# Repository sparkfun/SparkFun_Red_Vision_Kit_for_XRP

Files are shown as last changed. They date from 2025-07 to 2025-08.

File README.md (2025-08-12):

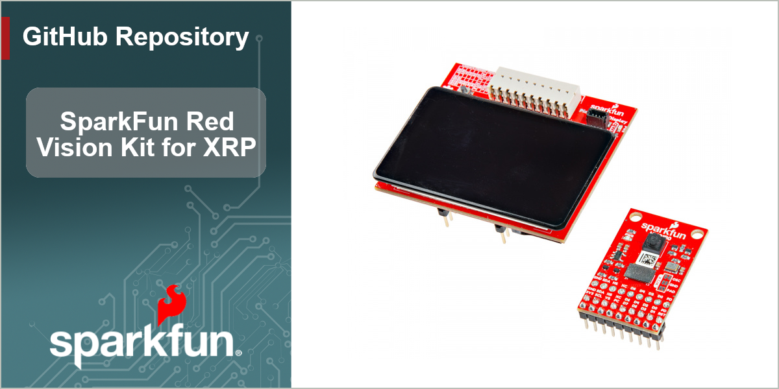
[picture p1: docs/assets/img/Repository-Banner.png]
SparkFun Red Vision Kit for XRP (https://www.sparkfun.com/sparkfun-pico-vision-kit-for-xrp.html)


[*SparkFun Red Vision Kit for XRP (KIT-28667)*](https://www.sparkfun.com/sparkfun-pico-vision-kit-for-xrp.html)

The SparkFun Red Vision Kit for XRP comes with the Red Vision Touch Display for Pico and Red Vision Camera Board - HM01B0 (Color) to add add machine vision capabilities to the Experiential Robotics Platform (XRP) Kit. This kit comes with everything you need to quickly and easily add a camera and touchscreen display to your XRP Robot with no soldering required. These boards let you add live image processing as well as advanced features including object and contour detection among others to the Experiential Robotics Platform (XRP) Kit using the SparkFun MicroPython Red Vision Code package, a MicroPython port of the popular OpenCV image processing library.

Repository Contents
-------------------

* **/Hardware** - KiCad design files (.brd, .sch)
* **/docs** - GitHub Pages documentation files

Documentation
--------------
* **[SparkFun Red Vision MicroPython Package](https://github.com/sparkfun/red_vision/tree/main)** - MicroPython package for the SparkFun Red Vision Kit for XRP.
* **[SparkFun MicroPython OpenCV](https://github.com/sparkfun/micropython-opencv)** - MicroPython port of OpenCV code library.
* **[SparkFun MicroPython Firmware Releases](https://github.com/sparkfun/micropython/releases)** - SparkFun MicroPython firmware releases.
* **[SparkFun Red Vision Kit for XRP Hookup Guide](https://docs.sparkfun.com/SparkFun_Red_Vision_Kit_for_XRP/introduction)** - Basic hookup guide for the SparkFun Red Vision Kit for XRP.

Product Versions
----------------
* [KIT-28667](https://www.sparkfun.com/sparkfun-pico-vision-kit-for-xrp.html) - Initial release of the SparkFun Red Vision Kit for XRP
* [LCD-29467](https://www.sparkfun.com/sparkfun-red-vision-touch-display-for-pico.html) - SparkFun Red Vision Touch Display for Pico (Standalone board)
* [SEN-29468](https://www.sparkfun.com/sparkfun-red-vision-camera-board-hm01b0-color.html) - SparkFun Red Vision Camera Board - HM01B0 (Color) (Standalone board)

License Information
-------------------

This product is _**open source**_! 

Please review the LICENSE.md file for license information. 

If you have any questions or concerns on licensing, please contact technical support on our [SparkFun forums](https://forum.sparkfun.com/viewforum.php?f=152).

Distributed as-is; no warranty is given.

- Your friends at SparkFun.

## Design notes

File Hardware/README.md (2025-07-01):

SparkFun <PRODUCT NAME> Design Files
=====================================

The .sch and .brd files hare are Eagle CAD schematic and PCB design files from SparkFun Electronics.
A freeware version of Autodesk Eagle can be found [here](https://www.autodesk.com/products/eagle/free-download).

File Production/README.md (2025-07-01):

SparkFun <PRODUCT NAME> Production Files
=========================================

These are the production files SparkFun uses for printing PCBs.

License Information
-------------------
This product is open source! 

The hardware is released under [Creative Commons ShareAlike 4.0 International](https://creativecommons.org/licenses/by-sa/4.0/).

Please use, reuse, and modify these files as you see fit. Please maintain attribution to SparkFun Electronics and release anything derivative under the same license.

Distributed as-is; no warranty is given.

- Your friends at SparkFun.

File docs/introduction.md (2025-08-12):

<figure markdown>
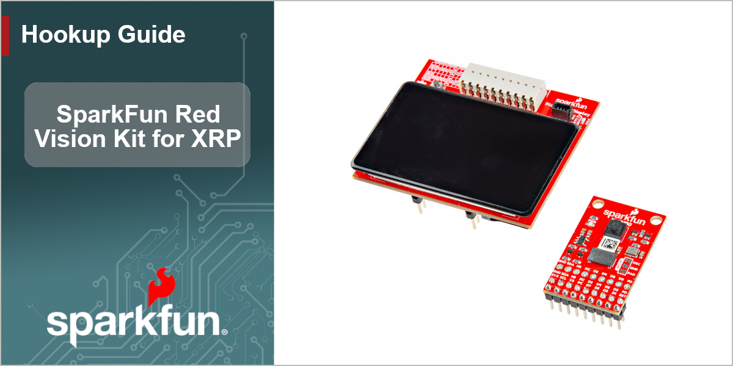
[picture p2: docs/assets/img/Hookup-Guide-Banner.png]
Banner photo for the Red Vision Kit for XRP

</figure>

The [SparkFun Red Vision Kit for XRP](https://www.sparkfun.com/sparkfun-pico-vision-kit-for-xrp.html) features the [SparkFun Red Vision Touch Display for Pico](https://www.sparkfun.com/sparkfun-red-vision-touch-display-for-pico.html) and the [SparkFun Red Vision Camera Board - HM01B0 (Color)](https://www.sparkfun.com/sparkfun-red-vision-camera-board-hm01b0-color.html) so you can add image processing and display to the SparkFun Experiential Robotics Kit (XRP). This Hookup Guide is written primarily for users with the Red Vision kit but those who have just one of these boards can follow along to some degree to get their boards up and running on an XRP or Pico. Note, all code covered here assumes use of the full Red Vision kit connected to an XRP Kit.

## Required Matierals

In order to follow along with this guide, you'll need the following materials:

* [SparkFun Red Vision Kit for XRP](https://www.sparkfun.com/sparkfun-pico-vision-kit-for-xrp.html)
* [SparkFun XRP Kit](https://www.sparkfun.com/experiential-robotics-platform-xrp-kit.html) (The Red Vision Kit does **not** work with the [Beta version](https://www.sparkfun.com/experiential-robotics-platform-xrp-kit-beta.html) of the XRP)
* [USB-C Cable](https://www.sparkfun.com/reversible-usb-a-to-c-cable-0-8m.html)

## Suggested Reading

This guide assumes users have a fully assembled and functioning XRP Kit and also is somewhat familiar with the XRP Code Editor. If you need help assembling your XRP Kit or getting started with the XRP and the XRP Code editor, please read through the following documentation:

* [XRP Users Guide](https://xrpusersguide.readthedocs.io/en/latest/course/introduction.html)
* [Experiential Robotics Platform Docs](https://introtoroboticsv2.readthedocs.io/en/latest/)

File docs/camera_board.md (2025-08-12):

Let's take a closer look at the Camera Board - HM0B10 and the hardware on it.

<figure markdown>
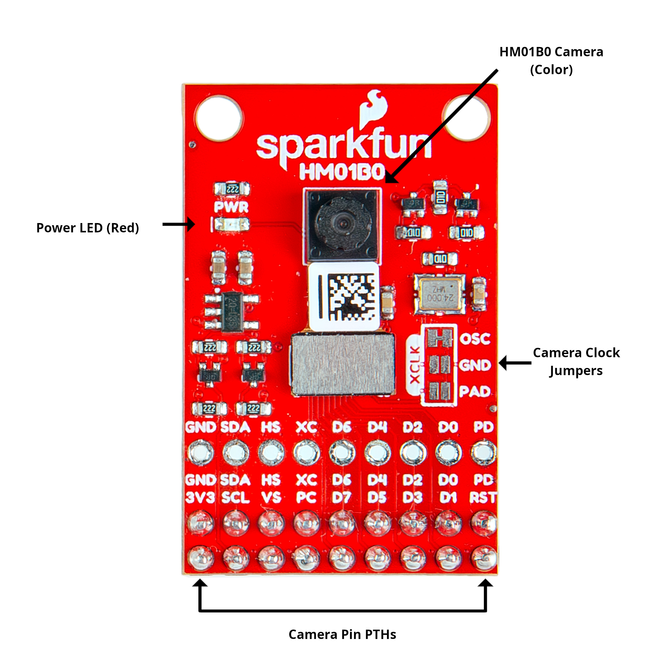
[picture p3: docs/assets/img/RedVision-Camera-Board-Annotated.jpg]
Annotated photo of the Red Vision Camera Board

</figure>

## Himax HM0B10 Camera Module (Color)

The HM0B10 camera module from Himax<sup>&reg;</sup> has a 320 x 320 pixel resolution that supports frame rates of up to 51FPS in full resolution (320x320) and up to 60FPS in windowed/QVGA (320x240) operation. The camera module also has a 2x2 monochrome binning mode that supports up to 120FPS if you're looking to maximize frame rate over resolution and color. The HM01B0 also has a motion detect feature tied to an interrupt output so you can program it to wake up your camera project whenever it senses motion. The video data interface communicates over a configurable 1, 4 or 8bit interface that features both video frame for synchronizing multiple cameras and line sync for creating a composite image from two cameras. The HM01B0 operates over a I<sup>2</sup>C serial interface with an address of <b>0x24</b>. For complete information on the HM0B10, refer to the [datasheet](https://cdn.sparkfun.com/assets/7/f/c/8/3/HM01B0-MNA-Datasheet.pdf).

## Pinout

The Camera Board breaks out all of the HM0B10's pins to three 9 pin, 0.1"-spaced plated through hole headers. The three headers are split into a single "top" header and a pair of "bottom" headers and we'll refer to them as "Top" and "Bottom" for the descriptions and tables below. Several pins are shared between the two sets. The Top header breaks out the minimum pins needed for basic use of the camera module and the Bottom header pair breaks out all the pins. This bottom pair connects directly to the 2x10 connector on the Red Vision Touch Display.

The tables below outline the pin name, type and function of the pins broken out to each header:

**Top Header Pinout**
<table>
    <tr>
        <th>Pin Label/Name</th>
        <th>Type</th>
        <th>Function</th>
    </tr>
    <tr>
        <td>GND/Ground</td>
        <td>Ground</td>
        <td>Ground</td>
    </tr>
    <tr>
        <td>SDA</td>
        <td>In/Out</td>
        <td>I<sup>2</sup>C Serial Data I/O (Open Drain)</td>
    </tr>
    <tr>
        <td>HS/HSYNC</td>
        <td>Output</td>
        <td></td>
    </tr>
    <tr>
        <td>XC/Clock</td>
        <td>Input</td>
        <td>Main/External Clock Input</td>
    </tr>
    <tr>
        <td>D6</td>
        <td>Output</td>
        <td>Data 6 Output</td>
    </tr>
    <tr>
        <td>D4</td>
        <td>Output</td>
        <td>Data 4 Output</td>
    </tr>
    <tr>
        <td>D2</td>
        <td>Output</td>
        <td>Data 2 Output</td>
    </tr>
    <tr>
        <td>D0</td>
        <td>Output</td>
        <td>Data 0 Output</td>
    </tr>
    <tr>
        <td>PD/Cam Powerdown</td>
        <td>Input</td>
        <td>Camera Voltage Regulator Enable</td>
    </tr>
</table>

**Bottom Header Pair Pinout**
<table>
    <tr>
        <th>Pin Label/Name</th>
        <th>Type</th>
        <th>Function</th>
    </tr>
    <tr>
        <td>GND/Ground</td>
        <td>Ground</td>
        <td>Ground</td>
    </tr>
    <tr>
        <td>3V3/3.3V</td>
        <td>Voltage Input</td>
        <td>Voltage Regulator 3.3V Input</td>
    </tr>
    <tr>
        <td>SDA</td>
        <td>In/Out</td>
        <td>I<sup>2</sup>C Serial Data I/O (Open Drain)</td>
    </tr>
    <tr>
        <td>SCL</td>
        <td>Input</td>
        <td>I<sup>2</sup>C Clock Signal</td>
    </tr>
    <tr>
        <td>HS/HSYNC</td>
        <td>Output</td>
        <td></td>
    </tr>
    <tr>
        <td>VS/VSYNC</td>
        <td>Output</td>
        <td>Frame Valid Output</td>
    </tr>
    <tr>
        <td>XC/Clock</td>
        <td>Input</td>
        <td>Main/External Clock Input</td>
    </tr>
    <tr>
        <td>PC/PCLOCK/SCK</td>
        <td>Output</td>
        <td>Pixel Clock or Serial Clock Output</td>
    </tr>
    <tr>
        <td>D6</td>
        <td>Output</td>
        <td>Data 6 Output</td>
    </tr>
    <tr>
        <td>D7</td>
        <td>Output</td>
        <td>Data 7 Output</td>
    </tr>
    <tr>
        <td>D4</td>
        <td>Output</td>
        <td>Data 4 Output</td>
    </tr>
    <tr>
        <td>D5</td>
        <td>Output</td>
        <td>Data 5 Output</td>
    </tr>
    <tr>
        <td>D2</td>
        <td>Output</td>
        <td>Data 2 Output</td>
    </tr>
    <tr>
        <td>D3</td>
        <td>Output</td>
        <td>Data 3 Output</td>
    </tr>
    <tr>
        <td>D0</td>
        <td>Output</td>
        <td>Data 0 Output</td>
    </tr>
    <tr>
        <td>D1</td>
        <td>Output</td>
        <td>Data 1 Output</td>
    </tr>
    <tr>
        <td>PD/Cam Powerdown</td>
        <td>Input</td>
        <td>Camera Voltage Regulator Enable</td>
    </tr>
    <tr>
        <td>RST/Reset</td>
        <td>Input</td>
        <td>Camera Voltage Regulator Reset</td>
    </tr>
</table>

## LED

The sole LED on this board is a red Power LED to indicate whenever the board has power over 3.3V. 

## Solder Jumpers

The Camera Board has six solder jumpers labeled: <b>OSC</b>, <b>GND</b>, <b>PAD</b>, <b>OSC_DIS</b>, <b>LED</b> and <b>I2C</b>. The lists below outlines each solder jumper's function, default state and any notes on their use. Note, manipulating these solder jumpers is only recommended for *advanced users* as they alter the functionality of the board, change the pins used by it and require knowledge of [working with jumper pads and PCB traces](https://learn.sparkfun.com/tutorials/how-to-work-with-jumper-pads-and-pcb-traces). 

**Oscillator Jumpers:**

These solder jumpers all adjust which oscillator source connects to the camera's external clock (XCLK) pin or to use the camera's internal oscillator. The board defaults to run at 24MHz with an on board oscillator. Make sure to only connect XCLK to a **single** source at a time otherwise unexpected behavior or damage may occur.

* <b>OSC</b>: This solder jumper enables the on board 24MHz oscillator by connecting it to the HM01B0's XCLK pin. It is CLOSED by default. Sever the trace in between the solder jumpers to open the jumper and disable the 24MHz clock source. 
* <b>PAD</b>: This solder jumper connects the HM0B10's XCLK pin to the PTH pads on the board labeled <b>XC</b> so users can connect an external clock source. The jumper is OPEN by default. Close the jumper to enable the <b>XC</b> pin. Make sure both the <b>OSC</b> and <b>GND</b> jumpers are OPEN when connecting a clock source to the <b>XC</b> pin. **Note:** When connected to the Red Vision Touch Display, this signal connects to GPIO3 on the XRP Control Board (or Pico).
* <b>GND</b>: This solder jumper pulls the HM0B10's XCLK pin to ground to enable the camera's internal 48MHz oscillator. It is OPEN by default. Close the jumper to enable the internal oscillator. Make sure both the <b>OSC</b> and <b>PAD</b> jumpers are OPEN before closing this jumper.
* <b>OSC_DIS</b>: This solder jumper controls whether the 28MHz oscillator on the board is on or off. It is OPEN by default and enables the crystal. Close the jumper to disable the 28MHz oscillator.

**Other Jumpers:**
* <b>LED</b>: The LED jumper completes the Power LED circuit and is CLOSED by default. Open the jumper to disable the Power LED.
* <b>I2C</b>: The I<sup>2</sup>C jumper pulls the camera's SDA and SCL lines to <b>3.3V</b> through a pair of resistors. This three-way jumper is CLOSED by default. Opening the jumper completely disables the pullup resistors on the SDA/SCL lines.

## Board Dimensions

The SparkFun Red Vision Camera Board - HMB010 measures 0.9" x 1.40" (22.86mm x 35.56mm) and has two mounting holes that fit a [4-40 screw]().

<figure markdown>
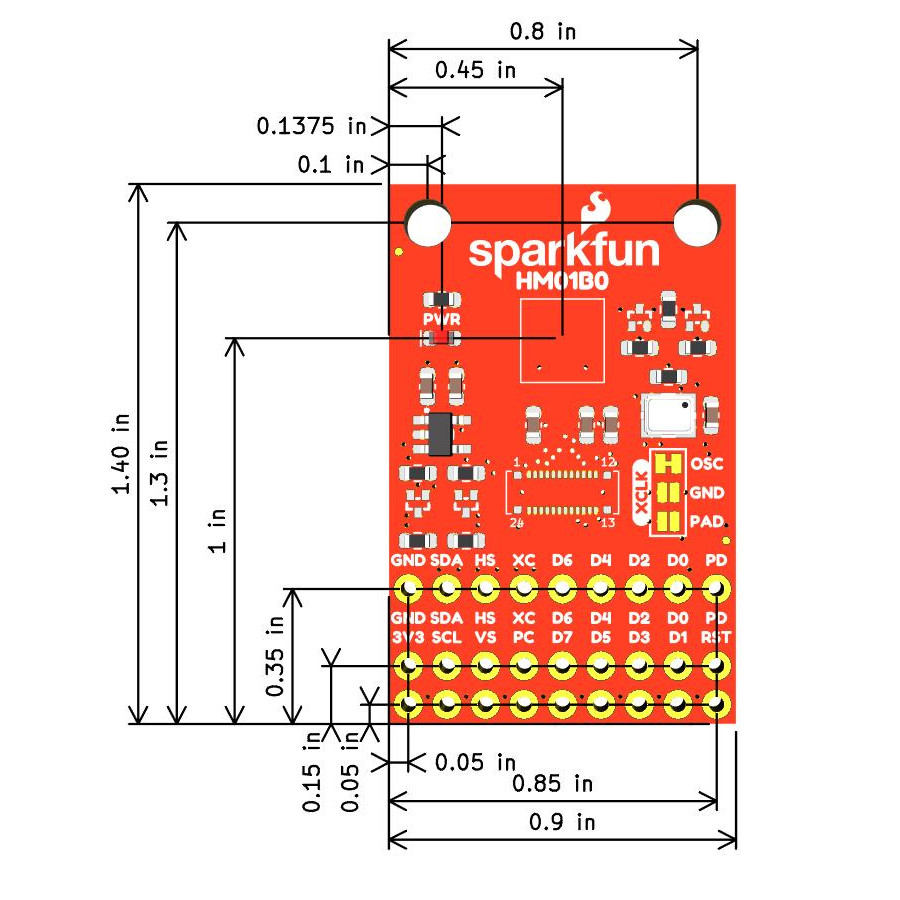
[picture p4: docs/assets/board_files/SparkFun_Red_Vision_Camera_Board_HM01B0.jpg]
Red Vision Camera Board dimensions

</figure>

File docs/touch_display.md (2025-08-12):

Let's take a closer look at the Red Vision Touch Display for Pico and the hardware included on it.

<figure markdown>
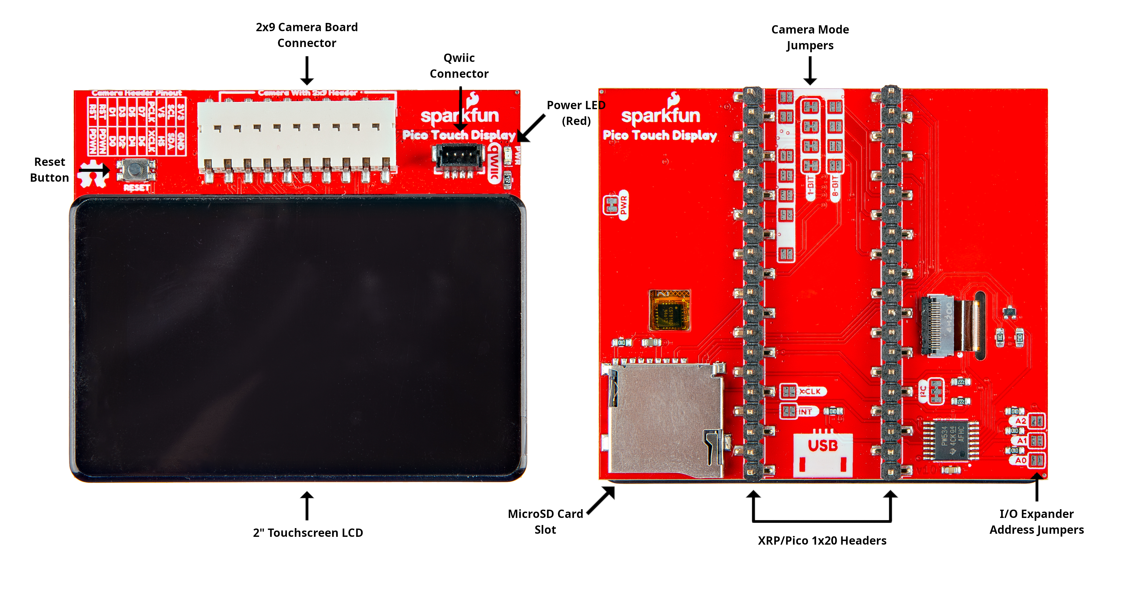
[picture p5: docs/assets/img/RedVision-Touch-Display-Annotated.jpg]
Annotated photo of the Red Vision Touch Display

</figure>

## 2" Capacitive Touch LCD

The Touch Display Board has a 2", 340x240px resolution capacitive touch LCD. 

## Connectors

### Pico Headers

We designed this board to mount directly to the XRP Control Board as well as a Rasbperry Pi Pico so it has a pair of 20 pin male headers that match the footprint of those two boards. These headers break out all the required pins for running and controlling both the display on this board as well as pins for the connected camera board. 

### Camera Connector

The Touch Display board has a 2x10 female connector to connect to the Red Vision Camera Board (or other compatible camera board, refer to [this list](https://github.com/sparkfun/red_vision?tab=readme-ov-file#hardware-support) for supported hardware). Note, the Camera Board has a 2x9 header so when connecting the two, make sure to align it to the side near the Qwiic connector. We cover this in more detail with photos in the [Hardware Assembly](../hardware_assembly.md) section further on in this guide.

### Qwiic Connector

The board has one Qwiic connector to allow users to easily add other Qwiic devices to their circuit if desired.

## GPIO Expander

The Touch Display includes a PCA9534PW GPIO expander to control several I/O (input and output) pins from the display, camera and SD card over I<sup>2</sup>C. Users can interact with the GPIO expander using the [SparkFun PCA9685 Python](https://github.com/sparkfun/qwiic_pca9685_py) package.

## &micro;SD Card Slot

The board includes a &micro;SD card slot to allow users to increase the memory capacity of a connected board; whether that be the XRP Control Board or a Pico.

## Reset Button

The reset button on the Touch Display board connects to the reset button on the XRP Control Board (or Pico) to allow easy access to reset the board.

## LED

The sole LED on this board is a red Power LED to indicate when the board has power.

## Solder Jumpers

The Red Vision Touch Display for Pico has a large amount of solder jumpers so we'll cover them in subsections. Note, manipulating these solder jumpers is only recommended for *advanced users* as they alter the functionality of the board, change the pins used by it and require knowledge of [working with jumper pads and PCB traces](https://learn.sparkfun.com/tutorials/how-to-work-with-jumper-pads-and-pcb-traces). 

### GPIO Expander Jumpers

This set of jumpers labeled <b>A0</b>, <b>A1</b> and <b>A2</b> control the I<sup>2</sup>C address of the GPIO Expander. All three jumpers are OPEN by default to set the GPIO Expander's address to <b>0x20</b>. Closing different combinations of these jumpers lets users select from eight I<sup>2</sup>C addresses. The table below outlines the different options to change the address. You can also refer to the [schematic](./assets/board_files/SparkFun_Red_Vision_Touch_Display_for_Pico.pdf) for more information.

<table>
    <tr>
        <th>I<sup>2</sup>C Address</th>
        <th>A0 State</th>
        <th>A1 State</th>
        <th>A2 State</th>
    </tr>
    <tr>
        <td>0x20 (Default)</td>
        <td>Open</td>
        <td>Open</td>
        <td>Open</td>
    </tr>
    <tr>
        <td>0x21</td>
        <td>Closed</td>
        <td>Open</td>
        <td>Open</td>
    </tr>
    <tr>
        <td>0x22</td>
        <td>Open</td>
        <td>Closed</td>
        <td>Open</td>
    </tr>
    <tr>
        <td>0x23</td>
        <td>Closed</td>
        <td>Closed</td>
        <td>Open</td>
    </tr>
    <tr>
        <td>0x24</td>
        <td>Open</td>
        <td>Open</td>
        <td>Closed</td>
    </tr>
    <tr>
        <td>0x25</td>
        <td>Closed</td>
        <td>Open</td>
        <td>Closed</td>
    </tr>
    <tr>
        <td>0x26</td>
        <td>Open</td>
        <td>Closed</td>
        <td>Closed</td>
    </tr>
    <tr>
        <td>0x27</td>
        <td>Closed</td>
        <td>Closed</td>
        <td>Closed</td>
    </tr>
</table>

The fourth jumper for the GPIO Expander controls whether or not the IC's enable pin connects to GPIO2 on the XRP Control Board. The jumper is OPEN by default. Close the jumper to connect the enable pin to GPIO2 for software control of the GPIO Expander.

### Camera Connections (DVP Interface) Jumpers

The solder jumper labeled <b>XCLK</b> allows users to generate an external clock to a connected camera from GPIO3. This jumper is OPEN by default. Closing this jumper connects the external clock pin on a connected camera to GPIO3 so make sure a connected camera is configured to use an external clock signal from this pin. **Note:** The Red Vision Camera Board included in this kit is configured to use an on-board external clock by default so *make sure* to adjust the board to use an external clock signal from GPIO3 prior to closing this jumper.

The two groups of solder jumpers labeled <b>1-BIT</b> and <b>8-BIT</b> allow users to change between running a connected camera in 1-Bit (Default) or 8-bit modes. Switching between 1-Bit and 8-Bit requires adjusting **all** of the related jumpers. For example, the board defaults to running a camera in 1-Bit mode by having **all** 1-Bit jumpers CLOSED and **all** 8-Bit jumpers OPEN. The tables below outline which pins a connected camera route to when set to run in 1-Bit or 8-Bit modes:

**1-Bit Camera Operation**
<table>
    <tr>
        <th>Camera Pin</th>
        <th>XRP/Pico Pin</th>
        <th>Notes</th>
    </tr>
    <tr>
        <td>CAM_DO</td>
        <td>GPIO12</td>
        <td>Camera Data 0 Out</td>
    </tr>
    <tr>
        <td>CAM_VS</td>
        <td>GPIO13</td>
        <td>Camera Frame Valid Output</td>
    </tr>
    <tr>
        <td>CAM_HS</td>
        <td>GPIO14</td>
        <td>Cam Line Valid Output</td>
    </tr>
    <tr>
        <td>CAM_PCLK</td>
        <td>GPIO15</td>
        <td>Camera Pixel Clock/Serial Clock Out</td>
    </tr>
</table>

**8-Bit Camera Operation**
<table>
    <tr>
        <th>Camera Pin</th>
        <th>XRP/Pico Pin</th>
        <th>Note</th>
    </tr>
    <tr>
        <td>CAM_DO</td>
        <td>GPIO8</td>
        <td>Camera Data 0 Out</td>
    </tr>
    <tr>
        <td>CAM_D1</td>
        <td>GPIO9</td>
        <td>Camera Data 1 Out</td>
    </tr>
    <tr>
        <td>CAM_D2</td>
        <td>GPIO10</td>
        <td>Camera Data 2 Out</td>
    </tr>
    <tr>
        <td>CAM_D3</td>
        <td>GPIO11</td>
        <td>Camera Data 3 Out</td>
    </tr>
    <tr>
        <td>CAM_D4</td>
        <td>GPIO12</td>
        <td>Camera Data 4 Out</td>
    </tr>
    <tr>
        <td>CAM_D5</td>
        <td>GPIO13</td>
        <td>Camera Data 5 Out</td>
    </tr>
    <tr>
        <td>CAM_D6</td>
        <td>GPIO14</td>
        <td>Camera Data 6 Out</td>
    </tr>
    <tr>
        <td>CAM_D7</td>
        <td>GPIO15</td>
        <td>Camera Data 7 Out</td>
    </tr>
    <tr>
        <td>CAM_PCLK</td>
        <td>GPIO20</td>
        <td>Camera Pixel Clock/Serial Clock Out</td>
    </tr>
    <tr>
        <td>CAM_VS</td>
        <td>GPIO21</td>
        <td>Camera Frame Valid Output</td>
    </tr>
    <tr>
        <td>CAM_HS</td>
        <td>GPIO22</td>
        <td>Cam Line Valid Output</td>
    </tr>
</table>

### Other Jumpers

The last jumpers we haven't covered are labeled <b>PWR</b> and <b>I2C</b>. The <b>PWR</b> solder jumper completes the Power LED circuit and is CLOSED by default. Open the solder jumper to disable the Power LED. The <b>I2C</b> jumper pulls the I<sup>2</sup>C data (SDA/GPIO4) and clock (SCL/GPIO5) pins to <b>3.3V</b> through a pair of <b>2.2k&ohm;</b> resistors. Open this three-way jumper to disable the pullup resistors on the I<sup>2</sup>C bus if necessary.

## Board Dimensions

The Red Vision Touch Display for Pico measures 2.00" x 2.225" (50.80mm x 56.515mm).

<figure markdown>
Red Vision Touch Display board dimensions
</figure>

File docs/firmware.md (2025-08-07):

The SparkFun Red Vision Kit for XRP requires updated firmware to run properly. This firmware updates the XRP Control Board with the right drivers to work with the Vision Kit and also includes all of the MicroPython OpenCV examples included in the package. In this section we'll go over where to find this firmware to download, how to upload it to your XRP Control Board and where to open the examples once you've assembled the Vision Kit onto your XRP Kit. 

!!! Note
    We recommend updating the firmware on the XRP Control Board prior to installing the Vision Kit boards onto it as the Touch Display makes it difficult to reach the RESET and BOOT buttons.

## Vision Kit MiroPython Firmware

First things first, we need to download the Red Vision Kit firmware UF2 file from GitHub. If you're not familiar with what a UF2 file is and want to learn more, read more about them in this [Make Code post](https://makecode.com/blog/one-chip-to-flash-them-all). The SparkFun Red Vision firmware UF2 file is available for download from the [SparkFun MicroPython Firmware Releases](https://github.com/sparkfun/micropython/releases) on GitHub. The firmware file is named **RED_VISION_MICROPYTHON_SPARKFUN_XRP_CONTROLLER** so you'll need to click the "Show all ## Files" button at the bottom of the list and then scroll down until you find the file. Download the "RED_VISION_MICROPYTHON_SPARKFUN_XRP_CONTROLLER" file and take note of where it is saved on your computer.

## Entering Boot Mode on the XRP

Next, put the XRP Control Board into Boot Mode using the following steps:

* Connect the XRP Control Board to your computer over USB-C.
* Locate the Reset and Boot buttons.
* Press and hold the BOOT button down.
* Press and release the RESET button (while still holding the BOOT button).
* Release the BOOT button and the XRP Control Board should open as a removable drive named "RP2350" on your computer.

<figure markdown>
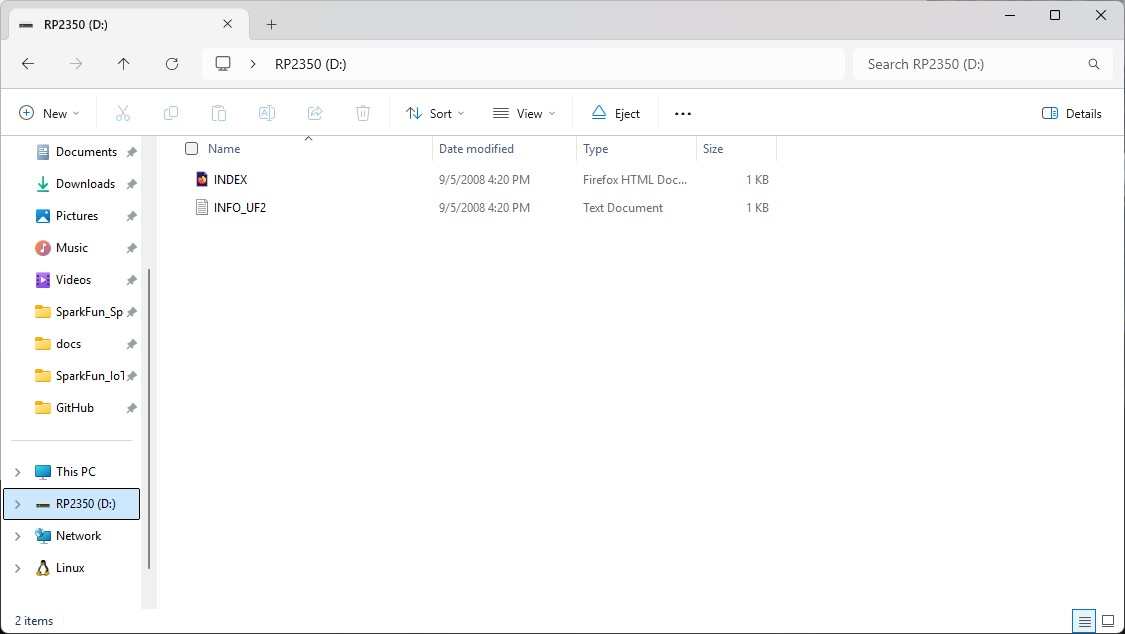
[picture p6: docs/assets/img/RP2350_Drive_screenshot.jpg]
Screenshot of XRP loaded as removable drive

</figure>

## Uploading Firmware

!!! note "Backup Your Files"
    Important! Make sure to back up any files/examples you have saved on your XRP as the new firmware *will* overwrite them.

Now that the XRP Control Board is in BOOT mode and open as a removable drive all we need to do is place the Vison Kit Firmware uF2 file in the XRP Control Board drive location. Open the download location for the firmware file and either drag the file over to the XRP drive or copy and paste it over. The upload can take about a minute to complete.

<figure markdown>
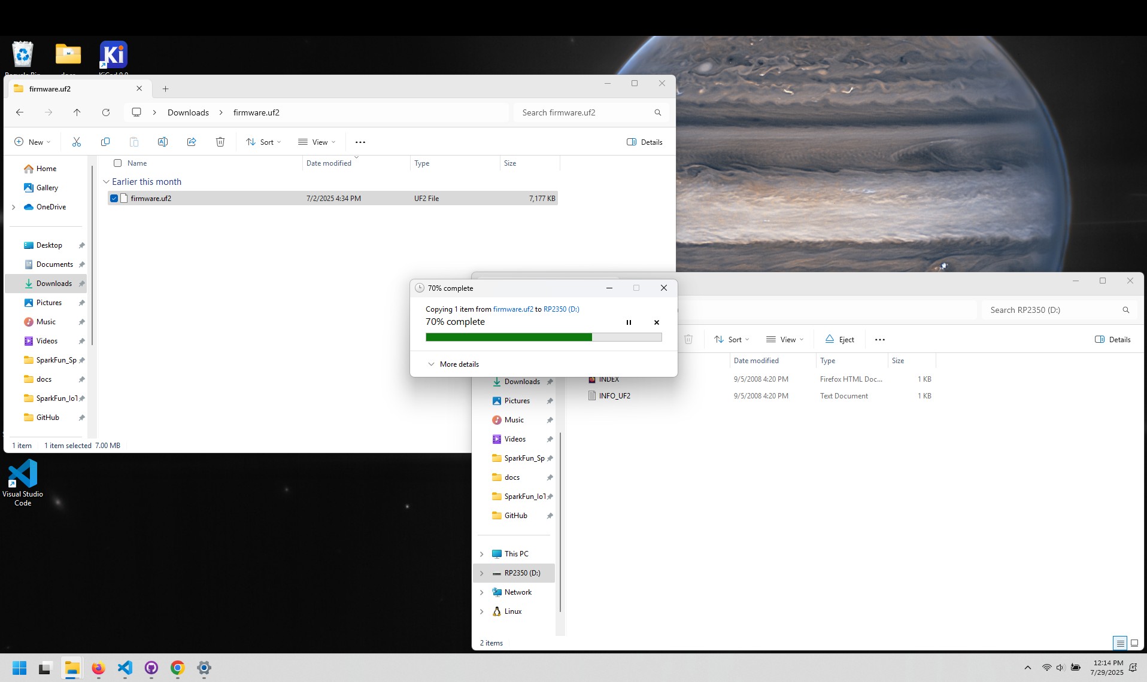
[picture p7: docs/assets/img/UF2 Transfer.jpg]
Screenshot showing firmware upload in progress

</figure>

After installing the firmware file, the XRP Control board should reset automatically and drop out of BOOT mode and we can move on to using the SparkFun MicroPython OpenCV examples.

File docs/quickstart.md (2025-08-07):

This Quick Start Guide covers how to get the SparkFun Red Vision Kit for XRP assembled and running on an XRP Kit and then use the Logo Recognition example to have the display identify and outline the SparkFun flame logo when the camera has it in view. This guide assumes users have an assembled XRP Kit, an understanding of how the kit functions as well as how to update XRP firmware and use the XRP Code Editor. If you're not familiar with those concepts or want to learn more about the boards included in the Red Vision Kit, uploading firmware and using the Red Vision MicroPython examples, read on to the Hardware and Software sections for more detailed information.

## XRP Red Vision Firmware

!!! note "Important!"
    Updating the firmware on the XRP Control Board will overwrite any files or settings saved on the board. Make sure to back up the contents of your XRP before updating the firmware.

Putting the XRP in Boot mode with the Red Vision Kit connected to it is a bit difficult so we'll update the firmware before connecting the Red Vision Kit with the following steps:

* Plug the XRP Control Board into your computer over USB-C.
* Download the latest release of the Red Vision MicroPtyhon Firmware from [GitHub](https://github.com/sparkfun/micropython/releases)
    * On the MicroPython releases page, click the "Show all ## assets" button at the bottom of the list and then download the UF2 file named **RED_VISION_MICROPYTHON_SPARKFUN_XRP_CONTROLLER**
* Put the XRP Control Board into BOOT mode with the following steps:
    * Press and hold the BOOT button
    * Press and release the RESET button (while holding the BOOT button)
    * Release the BOOT button.
    * Ensure the XRP Control Board appears as a removable storage device named "RP2350".
* Locate the "RED_VISION_MICROPYTHON_SPARKFUN_XRP_CONTROLLER" Firmware UF2 file and drag or copy/paste the file into the "RP2350" removable drive (This can take a while to complete.)

## Red Vision Kit Assembly with XRP

With the firmware updated, unplug the Control Board, power down the robot and then move on to assembling the Red Vision Kit with the following steps:

* Connect the Red Vision Camera Board to the Red Vision Touch Display for Pico taking care to align the Camera Board's 2x9 header to the LEFT side of the Touch Display's 2x10 connector. Refer to the photo below for proper alignment:

<figure markdown>
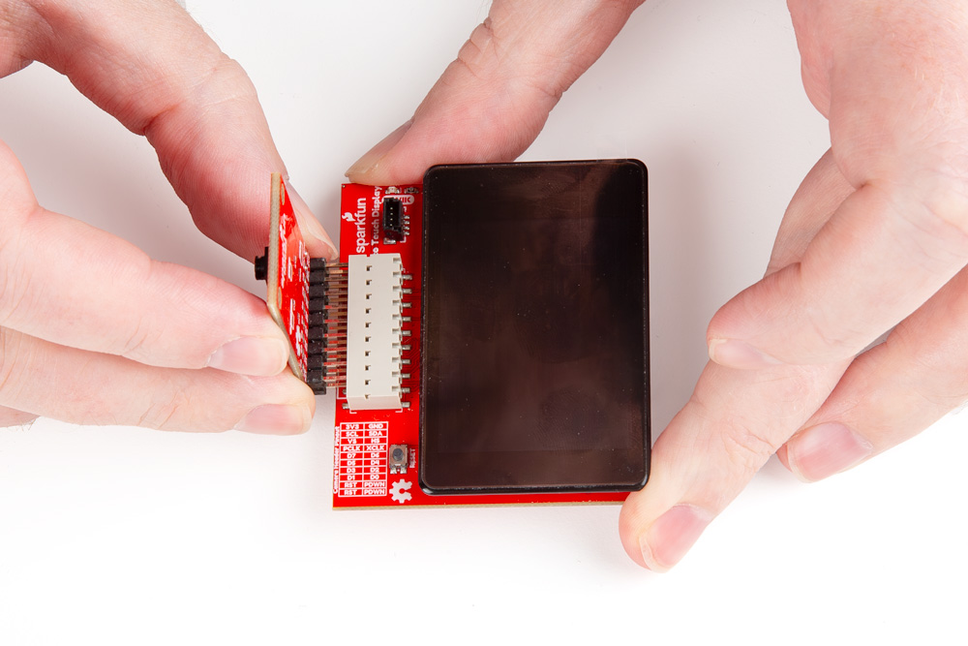
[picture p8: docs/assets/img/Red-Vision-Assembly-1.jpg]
Photo showing Camera Board connected to the Touch Display board

</figure>

* Plug the Red Vision Touch Display into the Control Board taking care to plug it into the "middle" set of headers on the Control Board:

<figure markdown>
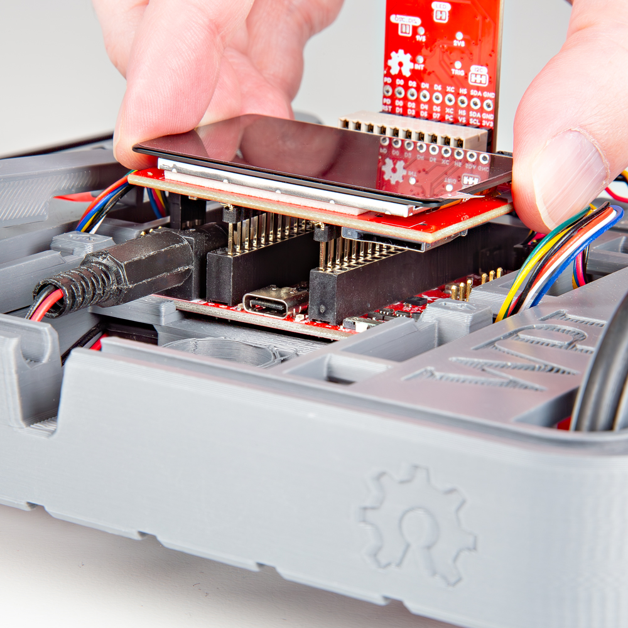
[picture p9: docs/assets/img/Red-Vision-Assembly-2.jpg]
Photo showing Touch Display connecting to the Control Board

</figure>

Take care to make sure the Pico Touch Display is plugged in facing toward the *front* of the XRP robot and is connected fully to the correct set of headers. It is possible to connect only one set of pins on the Touch Display board to the XRP Control Board's headers and this can cause damage to the boards in the Red Vision Kit. If your assembly looks like the photo below, do *not* power up the board and reseat the Touch Display:

<figure markdown>
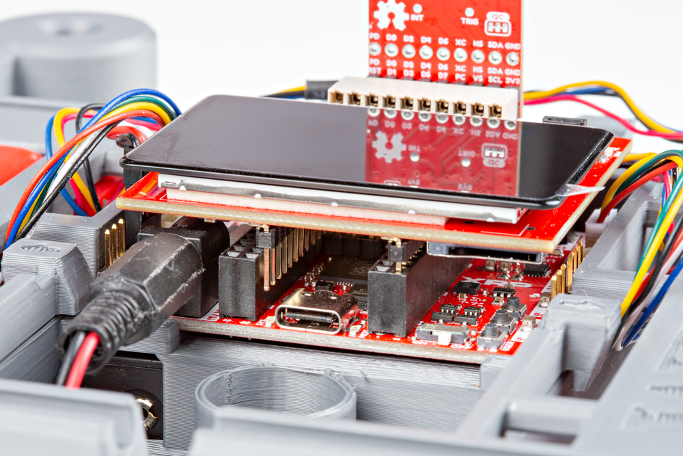
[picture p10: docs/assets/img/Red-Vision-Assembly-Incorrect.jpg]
Photo showing incorrect seating of Touch Display board

</figure>

## Example Code

Now that we've got the proper firmware installed and the Red Vision Kit connected to the XRP robot, let's take a look at the SparkFun Logo Recognition example included with the firmware. Upload the example by following the steps below:

* Open the [XRP Code Editor](https://xrpcode.wpi.edu/) in a Chromium<sup>&trade;</sup>C based browser (Chrome, Edge, etc.)
    * If you have not already, set the main power switch on the XRP Control Board to "On". The XRP Code Editor has a pop-up for this as well if you try and run code without the board powered on fully.
* Connect the XRP to the Code Editor. The window may open a pop-up asking to update the firmware. Click "Cancel" as updating the firmware will overwrite the MicroPython OpenCV firmware. A second pop-up may open asking to update libraries, click "Ok" to update the libraries. This will *not* affect the behavior or examples and is necessary to run other XRP examples.
* Open the folder named "red_vision_examples" and double click the file named "ex06_detect_sfe_logo.py" to open the code.
* Next, click the green "RUN" button in the top-right of the XRP Code Editor window.
* With the code running, we've printed out a black and white image with three objects on it; a star, the SparkFun flame and a heart. When holding it in front of the camera it should outline it and give information on the size and location of the logo. If you'd like to replicate this at home, just hold up your SparkFun red box or another SparkFun board point the logo on it at the camera. It should identify it; outline it and give information on the size and location of the logo similarly to the photo below:

<figure markdown>
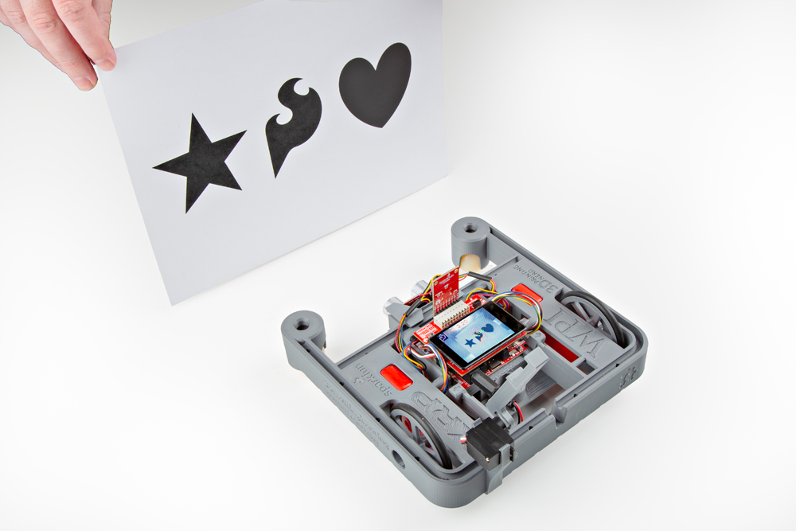
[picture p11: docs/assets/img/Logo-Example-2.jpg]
Photo showing the SparkFun logo detected and displayed on the Touch Screen display

</figure>

This close-up photo offers a better view of what the Touch Screen Display shows when the SparkFun logo is detected in camera frame. You can see in the top left what contour the code is looking for, the bounding box and outline of the logo along with information on the position of the logo's center on the screen (green numbers) and the size of the bounding box (white numbers).

<figure markdown>
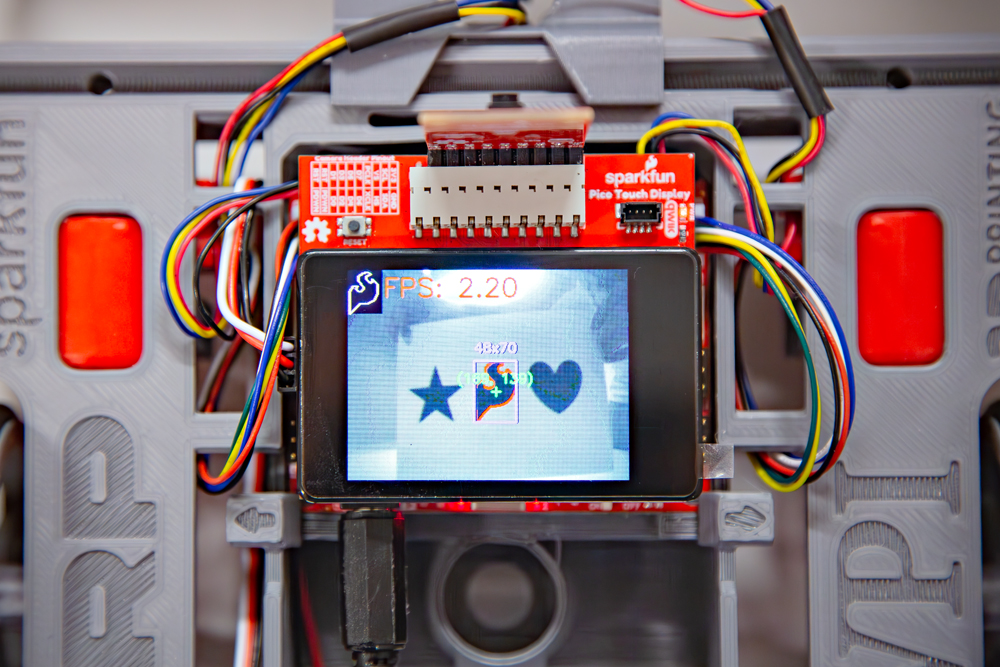
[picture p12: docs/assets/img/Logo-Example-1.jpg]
Close up photo showing the SparkFun logo detected and outlined on the Touch Screen display

</figure>

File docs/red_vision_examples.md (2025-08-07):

Now that we have the XRP Code editor up and running with our XRP Kit connected, let's take a look at some of the examples.

## Example 01 - Hello OpenCV

The first example is set up as a hardware test for the Touch Display board and the LCD. It initializes the display and creates a template image of text and shapes. On the left-hand side of the XRP Code editor, open the Red Vision Examples folder and double-click on "ex01_hello_opencv.py". Once it opens, click the green "Run" button in the top-right of the window. You should see the display initialize and then show the image below:

<figure markdown>
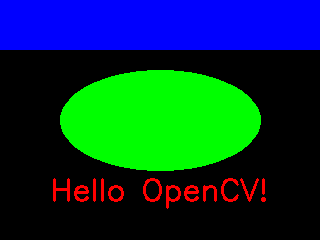
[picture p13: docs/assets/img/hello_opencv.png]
Demo image from Example 01 - Hello Open CV

</figure>

## Example 02 - Camera

The second example performs a similar hardware test but this time for the Camera Board and the HM0B10. It initializes both the camera and display, shows a quick splash image and then shows whatever the camera sees on the display. In the Red Vision Examples folder, double-click on "ex02_camera.py". After opening the file, click the "Run" button and you should see the display initialize with the splash screen pictured below followed by a greyscale stream of what the camera is viewing. 

<figure markdown>
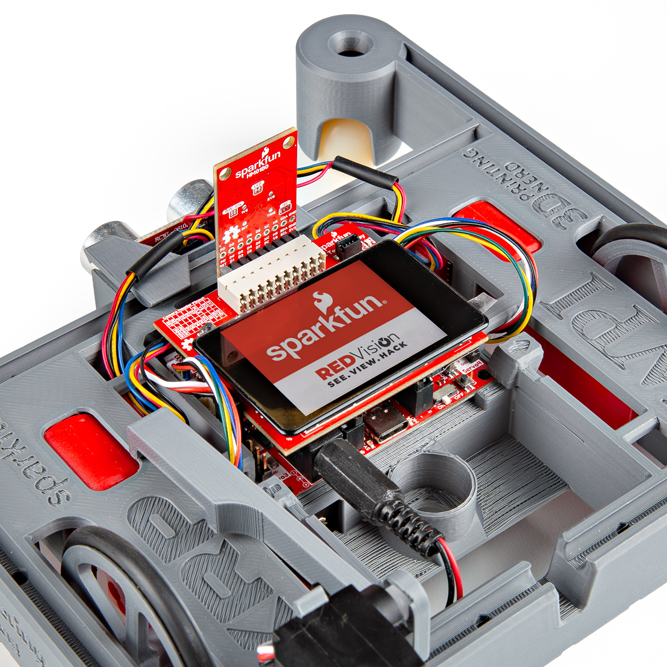
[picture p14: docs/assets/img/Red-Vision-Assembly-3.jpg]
Photo of splash screen on the Touch Display mounted on the XRP Robot

</figure>

Try moving the camera around or placing objects in front of it to test the video stream.

## Example 03 - Touch Screen

The third example tests the touch screen functionality by "turning on" pixels touched by a finger or other capacitive source (stylus, etc.). Double-click on "ex03_touch_screen.py" in the OpenCV Examples folder and click the "Run" button. The screen initializes with the same splash display as before and then follows it with a black screen with "Touch to Draw" printed in white text at the top of the screen. Try moving your finger across the display to draw or write something and you should see the display update following that path. It's not extremely precise as it's just a 240x240px display but you can draw a frumpy smiley face like the image below:

<figure markdown>
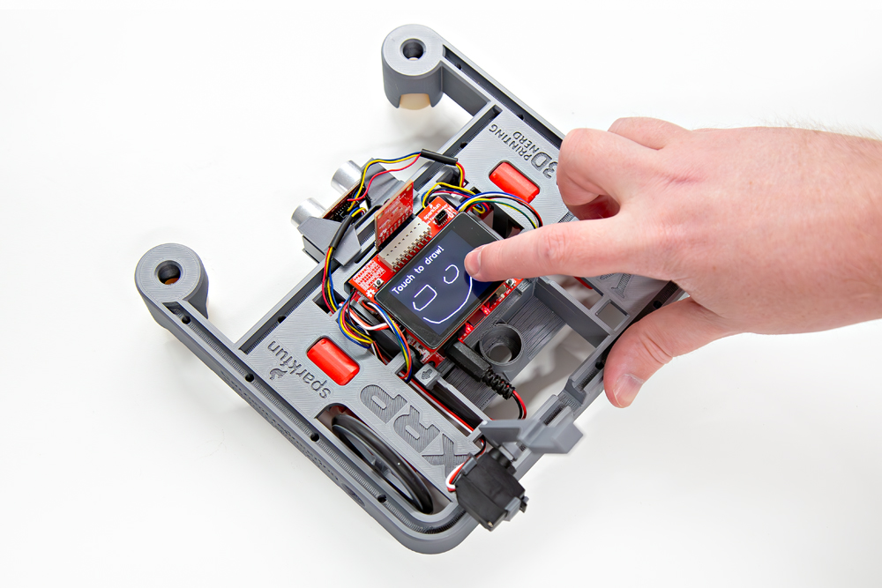
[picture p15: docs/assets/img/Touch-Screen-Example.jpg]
Photo showing a smiley face drawn on the touch display.

</figure>

## Example 06 - Detect SFE Logo

The sixth example demonstrates how to use a basic vision processing pipeline. A pipeline is a sequence of steps used to extract meaningful data from an image. In this example, the pipeline attempts to have the camera detect the SparkFun flame logo using contour matching. In the XRP Code Editor, double click "ex_06_detect_sfe_logo.py" to open the example and click the "Run" button.

While the example is running, if the camera detects the logo in frame, it outlines it on the display and draws a bounding box along with a target over the center of the logo to show how to get useful numerical data from an image such as the position and size of an object:

<figure markdown>
Photo showing SparkFun flame detected and outlined on Touch Display
</figure>

For our testing we have a nice big black and white print out with three objects on it; a star, SparkFun flame and heart. Now you may not have the same thing handy but if you've got a SparkFun red box or SparkFun board, try holding that up to the camera with the SparkFun flame in frame and the code should recognize it and outline it on the display just like the image above.

## XRP Example 01 - Touch Drive

The next two examples are nested in another folder within the "red_vision_examples" folder called "xrp_examples". Click on the "xrp_examples" folder to open it up and then double-click on the example named "ex01_touch_screen_drive.py" to open the code. This example creates a simple touch screen interface to drive the XRP robot. It displays four arrows to drive the robot forwards, backwards and to turn it left and right along with a stop button to exit the example.

<figure markdown>
Short video showing XRP robot turning from Touch Display input
</figure>

## XRP Example 02 - Grab Orange Ring

The second XRP example demonstrates how to combine object presence and position along with driving the robot towards the detected object. This takes a lot of what we've covered in the previous examples and puts them all together. Open the example in the XRP Code Editor by double clicking "ex02_grab_orange_ring.py". This example requires a bit of setup so it waits on a user input from the USER button on the XRP Control Board. We start by lining the robot up facing the orange ring so the camera identifies the object, outlines it and gets positional and distance data to the ring:

<figure markdown>
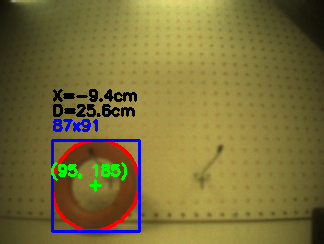
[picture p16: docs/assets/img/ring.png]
Photo showing camera view of the orange ring

</figure>

### Calculating Distance and Center Offset

Look closely at the image and you'll see the ring is not just outlined with pixel position data (95, 185), it also shows information on the offset from center of the camera's point of view (X=-9.4cm) as well as the approximate distance to the ring (D=25.6cm). We calculate the distance to the ring using the following formula: 

distance_cm = diameter_cm * focal_length_px / diameter_px

We're solving for "distance_cm" so we need the real world diameter of the ring (diameter_cm=12.7cm), the focal length pixel size (focal_length_px = 660 / 3.6) and the diameter of the ring in pixels (diameter_px = max(width, height)). 

Now that we have the approximate distance, we use that information to solve for how far left (negative units) or right (positive units) the ring is from the center in real world units using the following formula:

position_x_cm = distance_cm * position_x_px / focal_length_px

In the image above you'll see this ends up measuring as -9.4cm so the camera sees the ring as roughly 9.4cm left of center.

### User Input and Movement

Alright, that's enough math, let's see the robot move and grab the ring! Once you see the ring outlined on the Touch Display with values for distance and offset, press the USER button and the XRP robot will start navigating toward the ring and once it thinks it's in the right spot will lift the servo arm to grab the ring:

<figure markdown>
Video showing XRP robot driving toward and lifting the orange ring
</figure>

### Tips for Recreating Grab Ring Example

This example can be difficult to recreate on your own as it's looking for a specific object; an orange ring that is 12.7cm in diameter. If you'd like to try and recreate this example, you'll need to start with a ring roughly the same size and then adjust a few sections of the code depending on the size and color of the ring. The example specifically is looking for orange pixels so if your ring is a different color, you'll need to adjust the hue, saturation and value bounds for the color of your ring:

``` py
    # Here we use the `cv.inRange()` function to find all the orange pixels.
    # This outputs a binary image where pixels that fall within the specified
    # lower and upper bounds are set to 255 (white), and all other pixels are
    # set to 0 (black). This is applied to the HSV image, so the lower and upper
    # bounds are in HSV color space. The bounds were determined experimentally:
    # 
    # Hue: Orange hue is around 20, so we use a range of 15 to 25
    # Saturation: Anything above 50 is saturated enough
    # Value: Anything above 30 is bright enough
    lower_bound = (15, 50, 30)
    upper_bound = (25, 255, 255)
```

Next, measure the diameter of the ring and adjust line 122 in the example with the diameter in centimeters (cm):

``` py
diameter_cm = 12.7
```

Finally, this example attempts to drive the center of the XRP robot toward the orange ring so you'll need to position the servo arm on the front of the XRP robot as close as possible to the center of the robot similar to the position shown in the photo below:

<figure markdown>
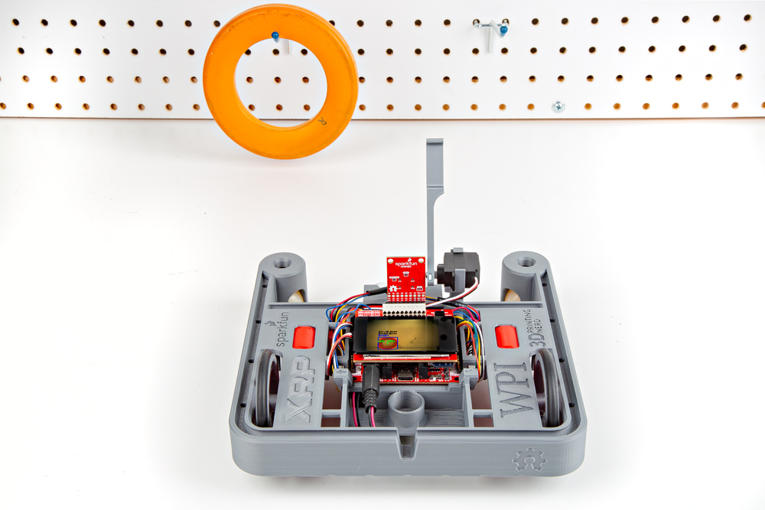
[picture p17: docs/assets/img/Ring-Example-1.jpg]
Photo showing servo arm positioned for Grab Orange Ring example

</figure>

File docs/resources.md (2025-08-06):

For more information about the Red Vision Kit for XRP along with the two boards included in it, check out the following resources:

**Red Vision Pico Touch Display**
* [Schematic](./assets/board_files/)
* [KiCad Files](./assets/board_files/SparkFun_Pico_Touch_Display.zip)
* [Board Dimensions](./assets/board_files/SparkFun_Red_Vision_Touch_Display_for_Pico.jpg)
* [GitHub Repository](https://github.com/sparkfun/SparkFun_Red_Vision_Touch_Display_for_Pico)

**Red Vision Camera Board - HM01B0 (Color)**
* [Schematic](./assets/board_files/)
* [KiCad Files](./assets/board_files/SparkFun_Camera_Board_HM01B0.zip)
* [Board Dimensions](./assets/board_files/SparkFun_Red_Vision_Camera_Board_HM01B0.jpg)
* [HM01B0 Datasheet](https://cdn.sparkfun.com/assets/7/f/c/8/3/HM01B0-MNA-Datasheet.pdf)
* [GitHub Repository](https://github.com/sparkfun/SparkFun_Red_Vision_Camera_Board_HM01B0)

**SparkFun MicroPython and Red Vision Code**
* [SparkFun MicroPython Firmware Releases](https://github.com/sparkfun/micropython/releases)
* [SparkFun Red Vision Code Package](https://github.com/sparkfun/red_vision)
* [SparkFun MicroPython OpenCV Port](https://github.com/sparkfun/micropython-opencv)

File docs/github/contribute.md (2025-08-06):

# Contribute: Make an Augmentation!
Spot an improvement opportunity? Feel free to contribute to our open-source design and documentation. 

## :material-file-document-multiple:&nbsp;Improve our Documentation
All of this documentation can be modified by you! Please help us make it better.

* These pages are contained in the [`docs` folder](https://github.com/sparkfun/SparkFun_Red_Vision_Kit_for_XRP/tree/main/docs) of the [SparkFun Ambient Light Sensor - VEML7700 repository](https://github.com/sparkfun/SparkFun_Red_Vision_Kit_for_XRP).

<!-- ### :material-source-pull:&nbsp;Submit a Correction -->
### Submit a Correction

1. With a GitHub account, [fork this repository](https://github.com/sparkfun/SparkFun_Red_Vision_Kit_for_XRP/fork).
2. Add your corrections or improvements to the markdown file.
3. File a pull request with your changes, and enjoy making the ~~words~~ ~~worlds~~ world a better place.
	* Once received, the documentation specialist will automatically be notified.
	* We will review your suggested improvements to make sure they are correct and fit within our documentation standards.

## :material-cog:&nbsp;Improve our Hardware Design
All of our designs are open-source! Please help us make it better.

* Our board design files are contained in the [`Hardware` folder](https://github.com/sparkfun/SparkFun_Red_Vision_Kit_for_XRP/tree/main/Hardware) of the [SparkFun Ambient Light Sensor - VEML7700 repository](https://github.com/sparkfun/SparkFun_Red_Vision_Kit_for_XRP).

<!-- ### :material-source-pull:&nbsp;Submit a Design Enhancement -->
### Submit a Design Enhancement

1. With a GitHub account, [fork this repository](https://github.com/sparkfun/SparkFun_Red_Vision_Kit_for_XRP/fork).
2. Add your design augmentation(s)
3. File a pull request with your changes, and enjoy making the ~~words~~ ~~worlds~~ world a better place.
	1. Once received, the engineer in charge of the original design will automatically be notified.
	2. We will review your suggested improvement(s) to verify that they are within our board design standards and meet our product design requirements.
	3. If approved, we will flag these changes for our next board revision. Congrats! 🍻

		!!! info
			Even if your suggestion is accepted, these changes may not be immediately available for purchase. We may have to cycle through our current product inventory first.

## Contributors&nbsp;:clap:
Let's provide some recognition to the contributors for this project!

GitHub Contributors Image
<br>


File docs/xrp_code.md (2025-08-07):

The SparkFun Red Vision Kit for XRP and SparkFun MicroPython OpenCV port can work on any MicroPython but since this guide focuses around using these boards on the XRP Kit, we'll be showing how to use these examples with the XRP Code Editor as it's tailored specifically to work with the XRP. 

## XRP Code Editor

The [XRP Code Editor](https://xrpcode.wpi.edu/) is a specialized web-based code editor for the XRP Kit to allow users to program in both Blocky and Python environments. We'll be using the Python environment. Note, the XRP Code Editor is only supported in Chromium<sup>&trade;</sup>C based browsers (Chrome, Edge, etc.).

### Connect XRP

First we need to connect the XRP to the XRP Code Editor by clicking the white "CONNECT XRP" button in the top right of the window and select "CONNECT VIA USB" in the pop-up window. Once the XRP connects you may see a pop-up asking to update the firmware. Click "CANCEL" as updating the firmware overwrites the Red Vision firmware we just installed:

<figure markdown>
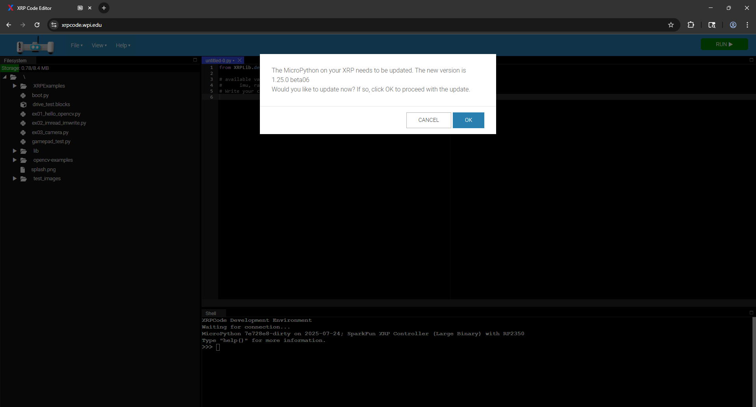
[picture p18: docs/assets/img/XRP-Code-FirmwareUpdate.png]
Screenshot showing update firmware pop-up in XRP Code Editor

</figure>

Now that we've got the XRP connected to the XRP Code Editor, we can move on to running the examples for the Red Vision Kit.

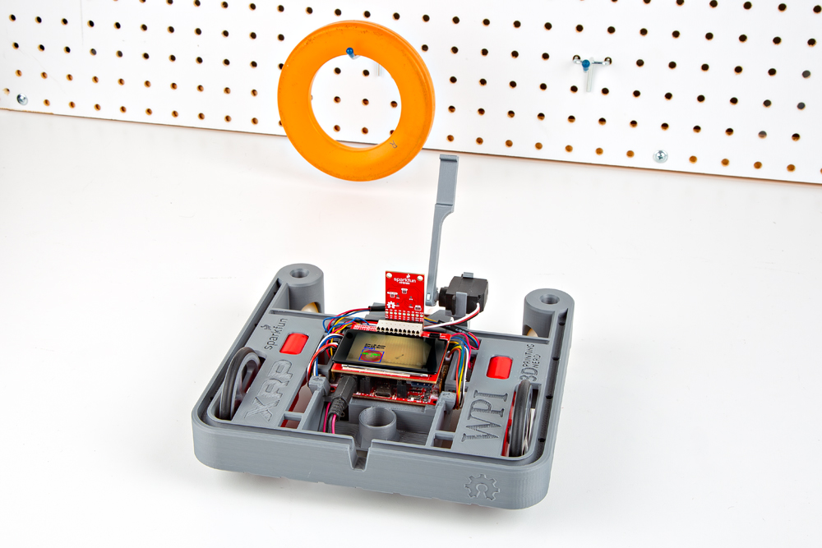
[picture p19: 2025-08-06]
docs/assets/img/Ring-Example-2.jpg

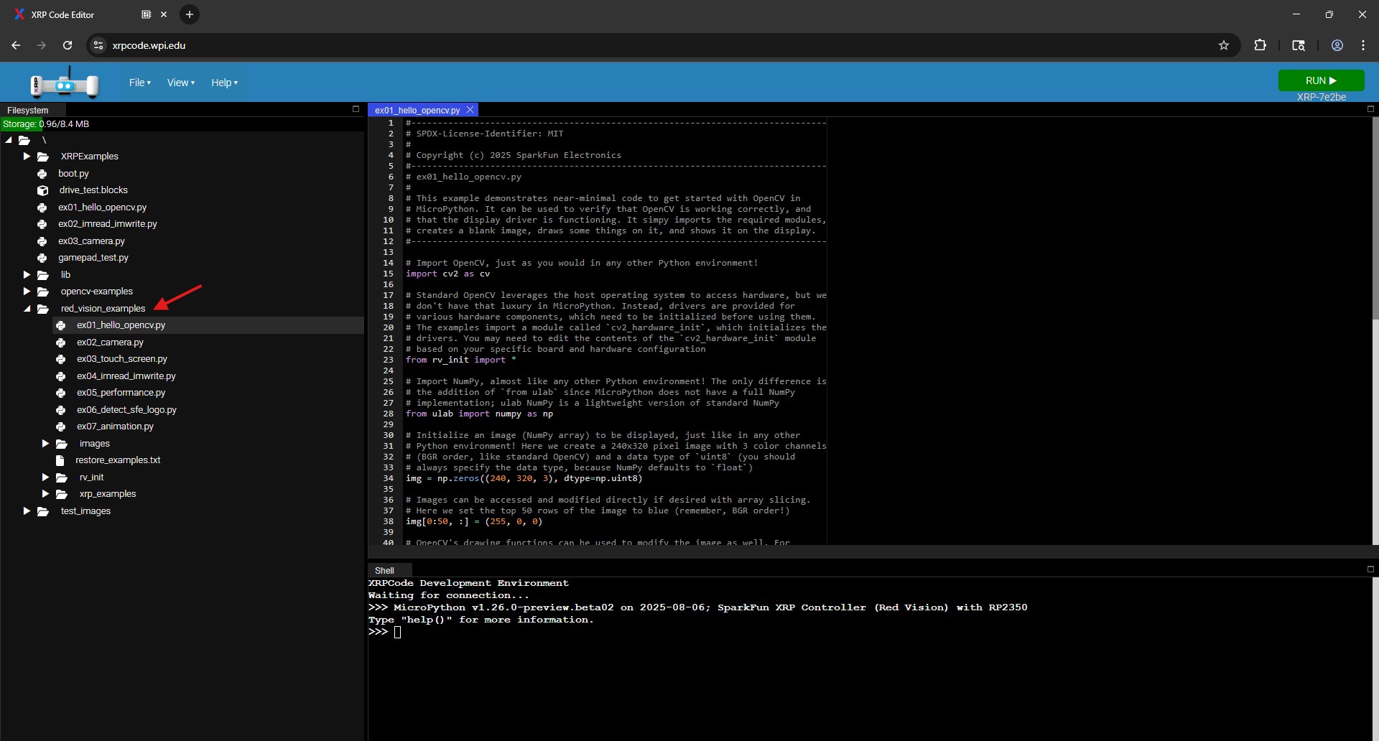
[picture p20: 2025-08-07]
docs/assets/img/XRP-Code-Red-Vision.jpg

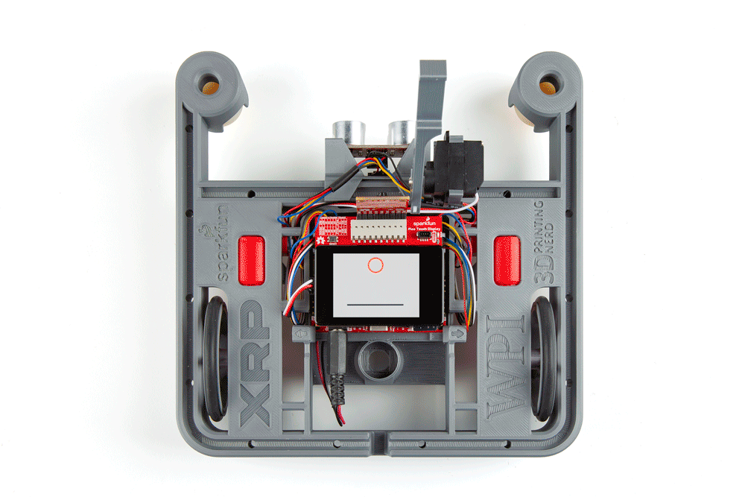
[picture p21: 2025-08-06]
docs/assets/img/Red-Vision-GIF-Bounce-Animation.gif

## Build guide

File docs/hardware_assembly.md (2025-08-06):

Now that we're familiar with the Vision Kit's Camera Board andTouch Display and have the updated firmware installed on the XRP Control Board, it's time to connect everything up to the XRP Kit.

## Connect Camera Board and Touch Display

Start by connecting the Camera Board to the Touch Display by plugging the 2x9 header on the Camera Board into the 2x10 header on the Touch Display. **IMPORTANT**: Make sure to align the Camera Board to the "LEFT" side of the 2x10 header on the Red Vision Touch Display like the photo below shows:

<figure markdown>
Photo showing Camera Board plugged into Touch Display
</figure>

## Connect Touch Display to XRP Control Board

Next, carefully align the pins on the bottom of the Red Vision Touch Display with the "Inner/Center" pair of connectors on the XRP Control Board like the photo below:

<figure markdown>
Photo showing Touch Display being connected to XRP Kit
</figure>

Take care to make sure the Red Vision Touch Display is plugged in facing toward the FRONT of the XRP robot and is connected fully to the correct set of headers. It is possible to connect only one set of pins on the Touch Display board to the XRP Control Board's headers and this can cause damage to the boards in the Red Vision Kit. If your assembly looks like the photo below, do *not* power up the board and reseat the Touch Display:

<figure markdown>
Photo showing incorrect seating of Touch Display board
</figure>

Now that we've got our Red Vision Kit assembled and connect to the XRP robot, let's move on to some code examples!

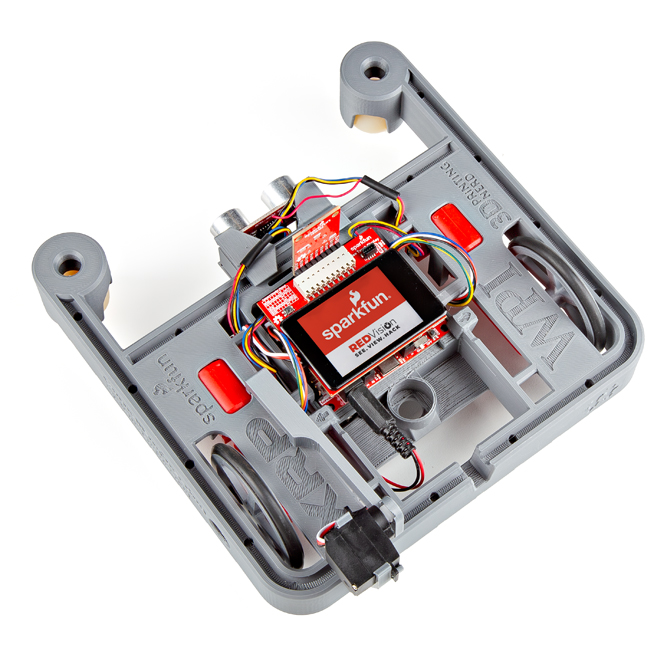
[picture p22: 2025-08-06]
docs/assets/img/Red-Vision-Assembly-4.jpg

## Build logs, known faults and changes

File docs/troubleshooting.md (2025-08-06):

## Red Vision Assembly Tips

### Camera Board Alignment

Make sure to align the Camera Board to the "LEFT" side of the 2x10 header on the Red Vision Touch Display like the photo below shows:

<figure markdown>
Photo showing Camera Board plugged into Touch Display
</figure>

### Touch Display Alignment

Take care to make sure the Red Vision Touch Display is plugged in facing toward the FRONT of the XRP robot and is connected fully to the correct set of headers. It is possible to connect only one set of pins on the Touch Display board to the XRP Control Board's headers and this can cause damage to the boards in the Red Vision Kit. If your assembly looks like the photo below, do *not* power up the board and reseat the Touch Display:

<figure markdown>
Photo showing incorrect seating of Touch Display board
</figure>

## SparkFun Red Vision Code Package Tips

The SparkFun MicroPython OpenCV port's [ReadMe file](https://github.com/sparkfun/red_vision?tab=readme-ov-file#sparkfun-red-vision) has comprehensive information about the entire package including detailed installation instructions, supported hardware, included OpenCV functions with descriptions of how to use them and much more.

### Hardware Configuration

The MicroPython port of OpenCV depends on hardware drivers to interface with cameras and displays. Drivers are built into the firmware, so there is no need to install them manually. 

An example module called cv2_hardware_init is imported by all examples to initialize the drivers. You will likely need to edit the files for your specific hardware and board configuration.

The standard MicroPython OpenCV firmware UF2 file contains a hardware configuration file set up specifically to work with the XRP Kit. If you're not using the Red Vision Kit with an XRP, you'll most likely need to go and change the pin assignments in the [cv2_hardware_init](https://github.com/sparkfun/micropython-opencv/blob/features_for_launch/examples/cv2_hardware_init)

### Performance

The main version of OpenCV is designed to run on desktop machines with orders of magnitude more processing power and speed so temper your expectations for the performance of this OpenCV port. 

## General Troubleshooting

!!! note
    <span class="glyphicon glyphicon-question-sign" aria-hidden="true"></span>
        <strong> Not working as expected and need help? </strong> <br /><br />

    If you need technical assistance and more information on a product that is not working as you expected, we recommend heading on over to the <a href="https://www.sparkfun.com/technical_assistance">SparkFun Technical Assistance</a> page for some initial troubleshooting. <br /><br />

    <div style="text-align: center"><a href="https://www.sparkfun.com/technical_assistance" target="sfe_technical_assistance" class="md-button">SparkFun Technical Assistance Page</a></div>

    If you don't find what you need there, the <a href="https://community.sparkfun.com/">SparkFun Forums</a> are a great place to find and ask for help. If this is your first visit, you'll need to create a forum account to search product forums and post questions.<br /><br />

    <div style="text-align: center"><a href="https://community.sparkfun.com/" class="md-button md-button--primary">Log Into SparkFun Forums</a></div>

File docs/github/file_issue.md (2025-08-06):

# Did we make a mistake?

Spot something wrong? Please let us know. 

## Discrepancies in the Documentation

All of our documentation can be modified by you! Please help us make it better.

* The documentation files for these pages are contained in the [`docs` folder](https://github.com/sparkfun/SparkFun_Red_Vision_Kit_for_XRP/tree/main/docs) of the [SparkFun Ambient Light Sensor - VEML7700 repository](https://github.com/sparkfun/SparkFun_Red_Vision_Kit_for_XRP).

### 🔍 Spot something wrong?

If a section of the documentation is incorrect, please [open an issue](https://github.com/sparkfun/SparkFun_Red_Vision_Kit_for_XRP/issues) and let us know.

### Do you have a suggested correction?

1. With a GitHub account, [fork this repository](https://github.com/sparkfun/SparkFun_Red_Vision_Kit_for_XRP/fork).
2. Add your correction(s) or improvement(s) to the markdown file(s)
3. File a pull request with your changes, and enjoy making the ~~words~~ ~~worlds~~ world a better place.
	* Once received, the documentation specialist will automatically be notified.
	* We will review your suggested improvement(s) to make sure they are correct and fit within our documentation standards.

## Problems in the Hardware Design

All of our designs are open-source! Please help us make it better.

* Our board design files are contained in the [`Hardware` folder](https://github.com/sparkfun/SparkFun_Red_Vision_Kit_for_XRP/tree/main/Hardware) of the [SparkFun Ambient Light Sensor - VEML7700 repository](https://github.com/sparkfun/SparkFun_Red_Vision_Kit_for_XRP).

### Does something not make sense? 🤔

If part of the design is confusing, please [open an issue](https://github.com/sparkfun/SparkFun_Red_Vision_Kit_for_XRP/issues) and let us know.

### Did we forget to include an important function of the board? 🤦

If part of the board's functionality is missing, please [open an issue](https://github.com/sparkfun/SparkFun_Red_Vision_Kit_for_XRP/issues) and file a feature request.

!!! tip "Design Considerations"
	Please keep in mind that we may intentionally exclude certain functions of the board to meet our product design requirements.
	
	* *For example, our Qwiic Micro boards are intended to fit on a small board layout and only use I<sup>2</sup>C communication; therefore, we may not have the SPI and interrupt pins available for users.*

### Do you wish to contribute directly to improving the board design?

1. With a GitHub account, [fork this repository](https://github.com/sparkfun/SparkFun_Red_Vision_Kit_for_XRP/fork).
2. Add your design augmentation(s)
3. File a pull request with your changes, and enjoy making the ~~words~~ ~~worlds~~ world a better place.
	1. Once received, the engineer in charge of the original design will automatically be notified.
	2. We will review your suggested improvement(s) to verify that they are within our board design standards and meet our product design requirements.
	3. If approved, we will flag these changes for our next board revision. Congrats! 🍻

		!!! info
			Even if your suggestion is accepted, these changes may not be immediately available for purchase. We may have to cycle through our current product inventory first.

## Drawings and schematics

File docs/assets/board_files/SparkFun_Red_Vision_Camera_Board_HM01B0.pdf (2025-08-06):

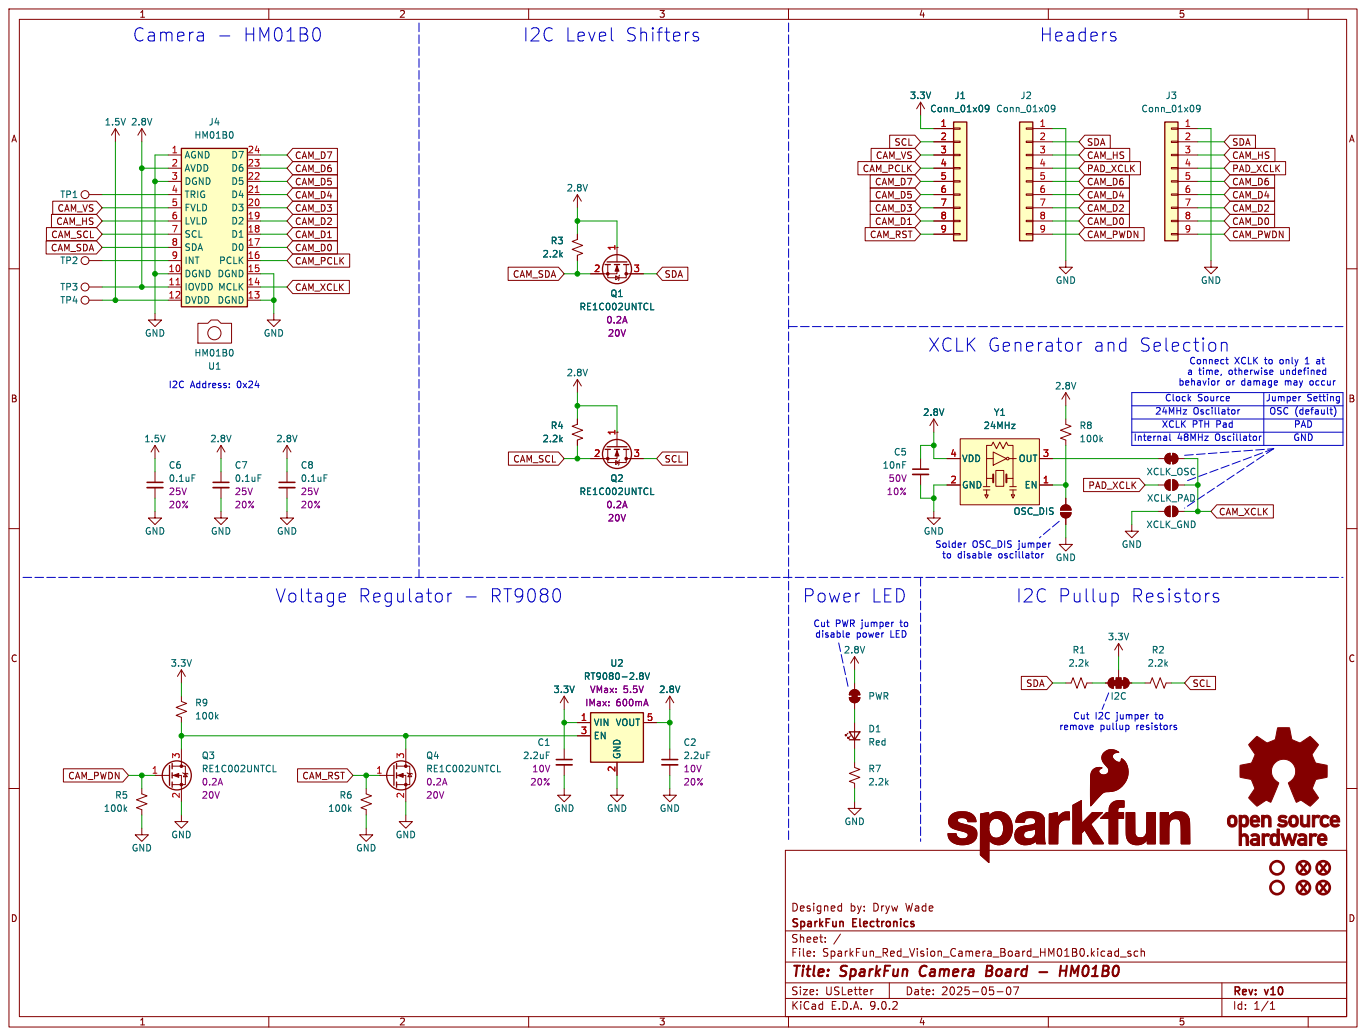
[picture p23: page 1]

AGND 1 AVDD 2 DGND 3 TRIG 4 FVLD 5

24MHz Oscillator XCLK Generator and Selection

behavior or damage may occur XCLK PTH Pad

Jumper Setting OSC (default) GND

remove pullup resistors Solder OSC_DIS jumper
to disable oscillator

Id: 1/1 Title: SparkFun Camera Board - HM01B0

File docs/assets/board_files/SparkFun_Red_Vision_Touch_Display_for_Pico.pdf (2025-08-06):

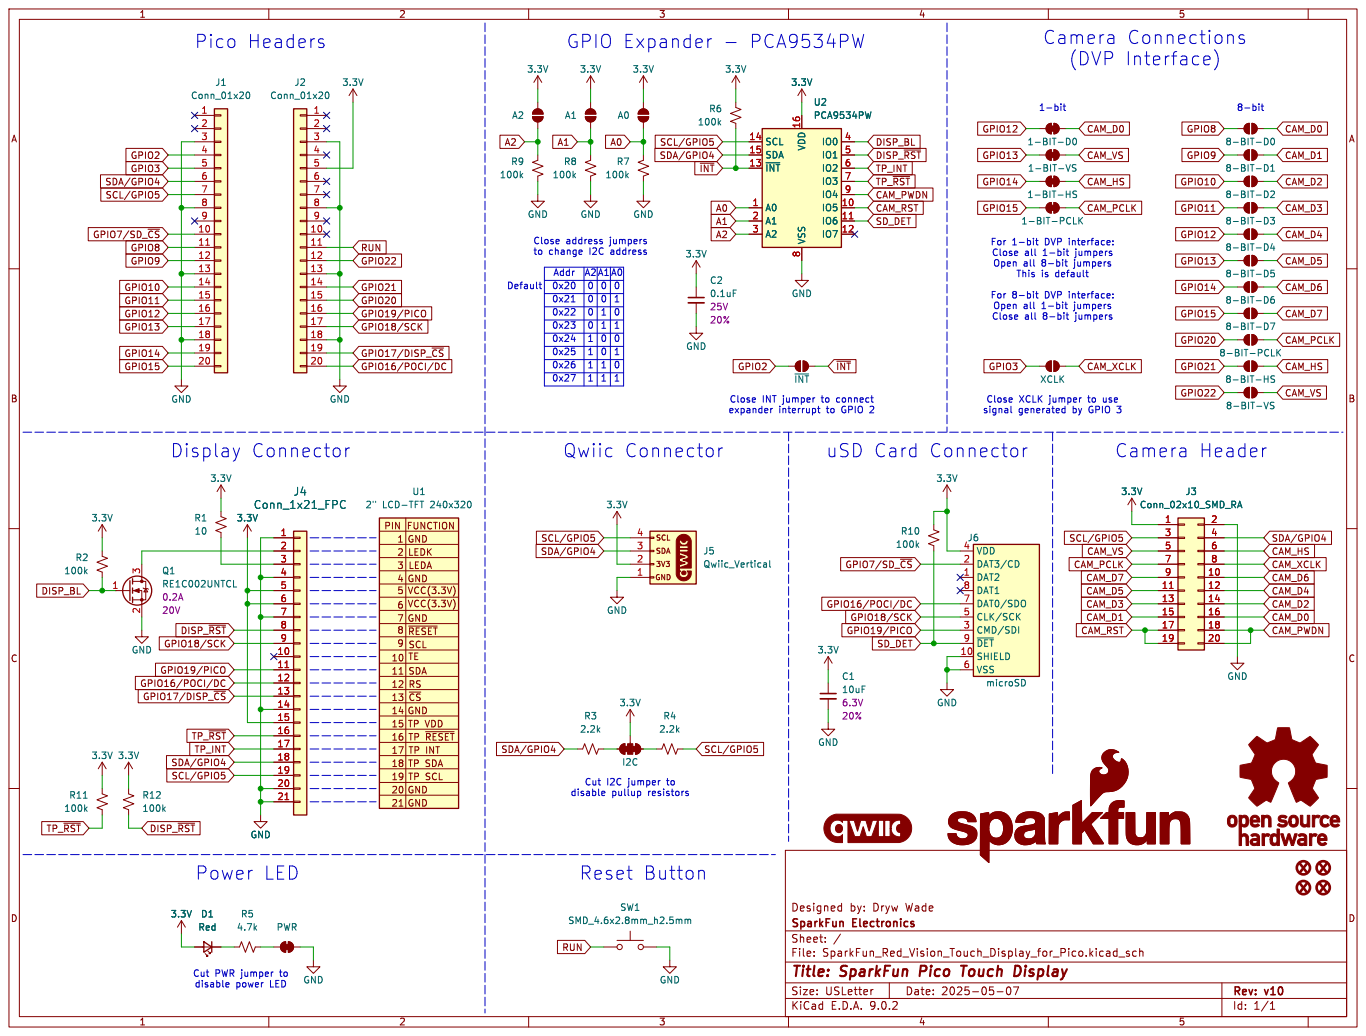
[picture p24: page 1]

2" LCD-TFT 240x320
~{CS} GND GND GND
LEDK
LEDA

SD_DET GPIO7/SD_~{CS} GPIO18/SCK GPIO16/POCI/DC

Id: 1/1 Title: SparkFun Pico Touch Display

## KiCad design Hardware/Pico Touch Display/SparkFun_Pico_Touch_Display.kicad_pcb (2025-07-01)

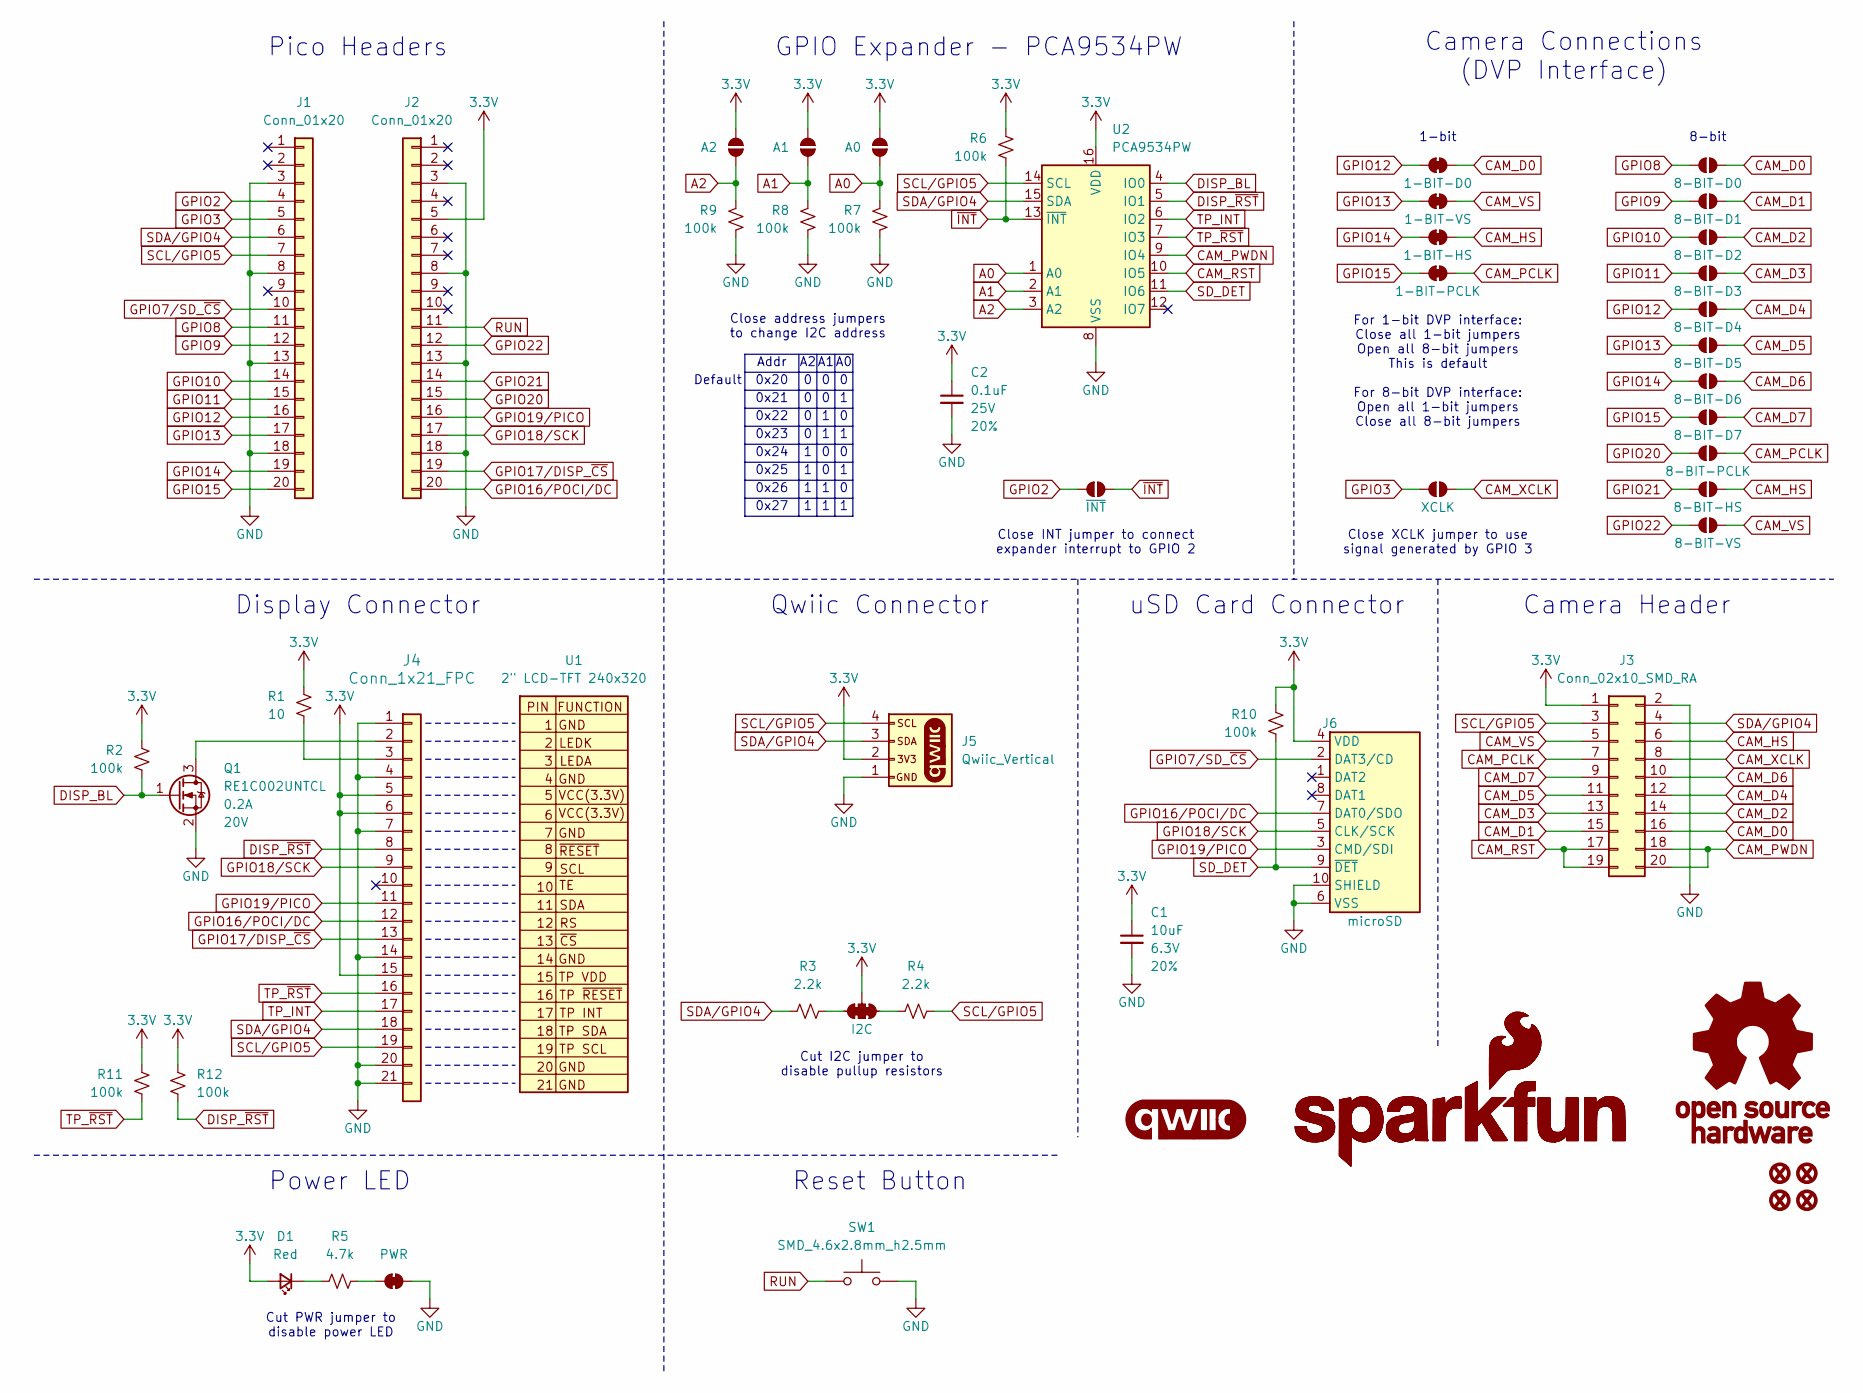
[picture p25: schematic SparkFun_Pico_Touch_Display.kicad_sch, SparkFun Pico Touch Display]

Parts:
C1: 10uF; C_0603_1608Metric; Voltage 6.3V; Tolerance 20%
C2: 0.1uF; C_0603_1608Metric; Voltage 25V; Tolerance 20%
D1: Red; LED_0603_1608Metric_Red
FID1, FID2, FID3, FID4: Fiducial_0.5mm; Fiducial_0.5mm_Mask1mm
G1: SparkFun_Logo; SparkFun_Logo_8mm
G2: SparkFun_Logo
G3: OSHW_Logo; Creative_Commons_License
G4: qwiic_Logo
J1, J2: Conn_01x20; 1x20_SMD_Pin1RightUp
J3: Conn_02x10_SMD_RA; 2x10_SMD_RA
J4: Conn_1x21_FPC; CONN21_FH35C-21S_HIR
J5: Qwiic_Vertical; JST_SMD_1.0mm-4_Vertical_Black
J6: microSD; microSD_External_Pin
JP1: I2C; Jumper_3_NC-2_Trace
JP2: 8-BIT-D0; Jumper_2_NO
JP3: 8-BIT-VS; Jumper_2_NO
JP4: 8-BIT-HS; Jumper_2_NO
JP5: 8-BIT-PCLK; Jumper_2_NO
JP6: 8-BIT-D3; Jumper_2_NO
JP7: 8-BIT-D2; Jumper_2_NO
JP8: 8-BIT-D1; Jumper_2_NO
JP9: 8-BIT-D4; Jumper_2_NO
JP10: 8-BIT-D5; Jumper_2_NO
JP11: 8-BIT-D6; Jumper_2_NO
JP12: 8-BIT-D7; Jumper_2_NO
JP13: XCLK; Jumper_2_NO
JP14: A0; Jumper_2_NO
JP15: A1; Jumper_2_NO
JP16: A2; Jumper_2_NO
JP17: 1-BIT-PCLK; Jumper_2_NC_Trace
JP18: 1-BIT-HS; Jumper_2_NC_Trace
JP19: 1-BIT-VS; Jumper_2_NC_Trace
JP20: 1-BIT-D0; Jumper_2_NC_Trace
JP21: PWR; Jumper_2_NC_Trace
JP22: ~{INT}; Jumper_2_NO
Q1: RE1C002UNTCL; SC-89 SOT-490
R1: 10; R_0603_1608Metric
R2, R6, R7, R8, R9, R10, R11, R12: 100k; R_0603_1608Metric
R3, R4: 2.2k; R_0603_1608Metric
R5: 4.7k; R_0603_1608Metric
SW1: SMD_4.6x2.8mm_h2.5mm; Push_SMD_4.6x2.8mm_h2.5mm
U1: 2" LCD-TFT 240x320; Waveshare_2_Inch_Outline
U2: PCA9534PW; TSSOP-16_4.4x5mm_P0.65mm

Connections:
3.3V: C1.1, C2.1, D1.2 (A), J2.5, J3.1, J4.5, J4.6, J4.15, J5.2, J6.4 (VDD), JP1.2 (B), JP14.2 (B), JP15.2 (B), JP16.2 (B), R1.2, R2.2, R6.2, R10.2, R11.2, R12.2, U2.16 (VDD)
A0: JP14.1 (A), R7.2, U2.1 (A0)
A1: JP15.1 (A), R8.2, U2.2 (A1)
A2: JP16.1 (A), R9.2, U2.3 (A2)
CAM_D0: J3.16, JP2.2 (B), JP20.1 (A)
CAM_D1: J3.15, JP8.1 (A)
CAM_D2: J3.14, JP7.1 (A)
CAM_D3: J3.13, JP6.1 (A)
CAM_D4: J3.12, JP9.1 (A)
CAM_D5: J3.11, JP10.1 (A)
CAM_D6: J3.10, JP11.1 (A)
CAM_D7: J3.9, JP12.1 (A)
CAM_HS: J3.6, JP4.2 (B), JP18.1 (A)
CAM_PCLK: J3.7, JP5.2 (B), JP17.1 (A)
CAM_PWDN: J3.18, J3.20, U2.9 (IO4)
CAM_RST: J3.17, J3.19, U2.10 (IO5)
CAM_VS: J3.5, JP3.2 (B), JP19.1 (A)
CAM_XCLK: J3.8, JP13.1 (A)
DISP_BL: Q1.1 (G), R2.1, U2.4 (IO0)
DISP_~RST: J4.8, R12.1, U2.5 (IO1)
GND: C1.2, C2.2, J1.3, J1.8, J1.13, J1.18, J2.3, J2.8, J2.13, J2.18, J3.2, J4.1, J4.4, J4.7, J4.14, J4.20, J4.21, J5.1, J6.6 (VSS), J6.10 (SHIELD), JP21.2 (B), Q1.2 (S), R7.1, R8.1, R9.1, SW1.2, U2.8 (VSS)
GPIO2: J1.4, JP22.2 (B)
GPIO3: J1.5, JP13.2 (B)
GPIO7/SD_~CS: J1.10, J6.2 (DAT3/CD)
GPIO8: J1.11, JP2.1 (A)
GPIO9: J1.12, JP8.2 (B)
GPIO10: J1.14, JP7.2 (B)
GPIO11: J1.15, JP6.2 (B)
GPIO12: J1.16, JP9.2 (B), JP20.2 (B)
GPIO13: J1.17, JP10.2 (B), JP19.2 (B)
GPIO14: J1.19, JP11.2 (B), JP18.2 (B)
GPIO15: J1.20, JP12.2 (B), JP17.2 (B)
GPIO16/POCI/DC: J2.20, J4.12, J6.7 (DAT0/SDO)
GPIO17/DISP_~CS: J2.19, J4.13
GPIO18/SCK: J2.17, J4.9, J6.5 (CLK/SCK)
GPIO19/PICO: J2.16, J4.11, J6.3 (CMD/SDI)
GPIO20: J2.15, JP5.1 (A)
GPIO21: J2.14, JP4.1 (A)
GPIO22: J2.12, JP3.1 (A)
unnamed: D1.1 (K), R5.2
unnamed: J4.2, Q1.3 (D)
unnamed: J4.3, R1.1
unnamed: JP1.1 (A), R4.1
unnamed: JP1.3 (C), R3.2
unnamed: JP21.1 (A), R5.1
RUN: J2.11, SW1.1
SCL/GPIO5: J1.7, J3.3, J4.19, J5.4, R4.2, U2.14 (SCL)
SDA/GPIO4: J1.6, J3.4, J4.18, J5.3, R3.1, U2.15 (SDA)
SD_DET: J6.9 (~DET), R10.1, U2.11 (IO6)
TP_INT: J4.17, U2.6 (IO2)
TP_~RST: J4.16, R11.1, U2.7 (IO3)
~INT: JP22.1 (A), R6.1, U2.13 (~INT)

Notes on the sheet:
1-bit
0x20
8-bit
Cut PWR jumper to disable power LED
0x22
0x27
0x24
GPIO Expander - PCA9534PW
Camera Connections (DVP Interface)
Close address jumpers to change I2C address
Default
Addr
Qwiic Connector
Cut I2C jumper to disable pullup resistors
Pico Headers
Camera Header
0x26
For 1-bit DVP interface: Close all 1-bit jumpers Open all 8-bit jumpers This is default For 8-bit DVP interface: Open all 1-bit jumpers Close all 8-bit jumpers
0x23
Display Connector
Close XCLK jumper to use signal generated by GPIO 3
0x21
uSD Card Connector
0x25
Power LED
Reset Button
Close INT jumper to connect expander interrupt to GPIO 2

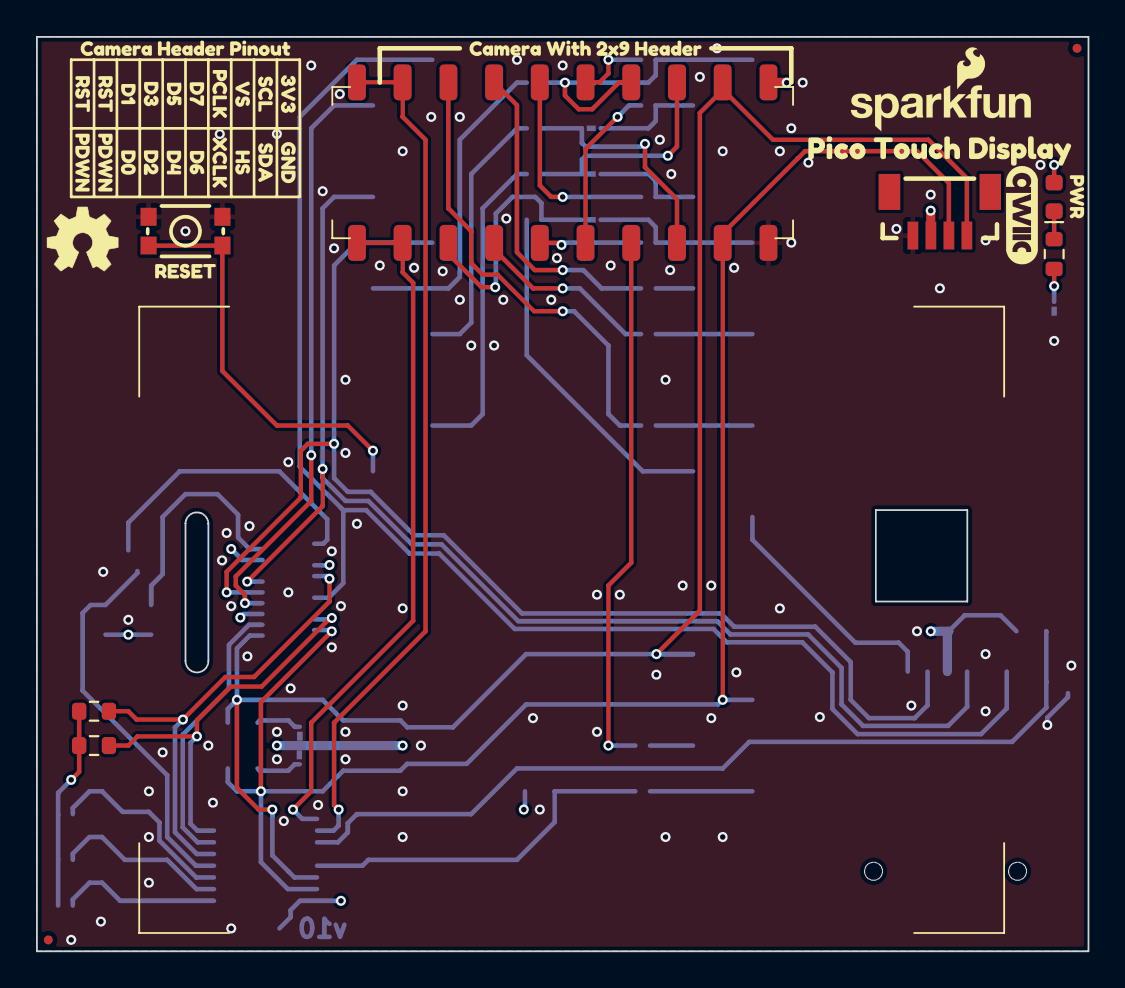
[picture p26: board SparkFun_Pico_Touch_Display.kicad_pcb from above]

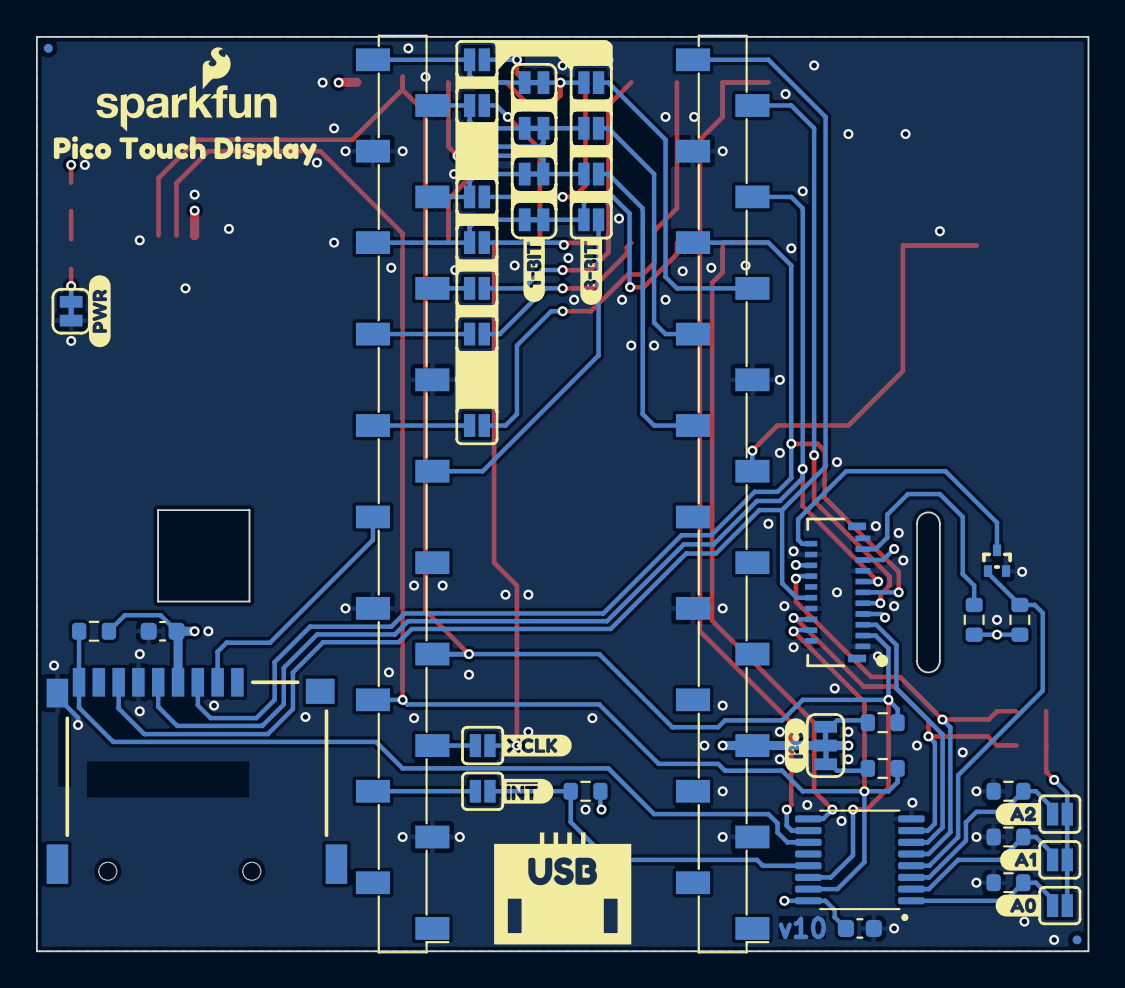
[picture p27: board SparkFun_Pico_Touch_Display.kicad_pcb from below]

Board: 4 copper layers, 58.4 x 50.8 mm, 89 parts (52 on the bottom side), 52 nets.

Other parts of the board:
Ref**: Val**; OSHW_Logo_4mm
kibuzzard-67A69C5F, kibuzzard-67A69C5F#2: G***; kibuzzard-67A69C5F
kibuzzard-67A69CD2, kibuzzard-67A69CD2#2: G***; kibuzzard-67A69CD2
kibuzzard-67A69CDC: G***; kibuzzard-67A69CDC
kibuzzard-67A69CE2: G***; kibuzzard-67A69CE2
kibuzzard-67A69CE6: G***; kibuzzard-67A69CE6
kibuzzard-67A69CEA: G***; kibuzzard-67A69CEA
kibuzzard-67A69CFF: G***; kibuzzard-67A69CFF
kibuzzard-67A69D0C: G***; kibuzzard-67A69D0C
kibuzzard-67A69D0F: G***; kibuzzard-67A69D0F
kibuzzard-67A69D1B: G***; kibuzzard-67A69D1B
kibuzzard-67A69D2C: G***; kibuzzard-67A69D2C
kibuzzard-67A69D2F: G***; kibuzzard-67A69D2F
kibuzzard-67A69D05: G***; kibuzzard-67A69D05
kibuzzard-67A69D16: G***; kibuzzard-67A69D16
kibuzzard-67A69D28: G***; kibuzzard-67A69D28
kibuzzard-67A69D32: G***; kibuzzard-67A69D32
kibuzzard-67A69E51: G***; kibuzzard-67A69E51
kibuzzard-67A69E55: G***; kibuzzard-67A69E55
kibuzzard-67ABB7DF: G***; kibuzzard-67ABB7DF
kibuzzard-67B3EC79, kibuzzard-67B3EC79#2: G***; kibuzzard-67B3EC79
kibuzzard-67B3EC92: G***; kibuzzard-67B3EC92
kibuzzard-67B3F617: G***; kibuzzard-67B3F617
kibuzzard-67B3FF40: G***; kibuzzard-67B3FF40
kibuzzard-67B3FF54: G***; kibuzzard-67B3FF54
kibuzzard-67B3FFE0: G***; kibuzzard-67B3FFE0
kibuzzard-67C124A5: G***; kibuzzard-67C124A5
kibuzzard-67C651AF: G***; kibuzzard-67C651AF
kibuzzard-67C1248C: G***; kibuzzard-67C1248C
kibuzzard-67C6452E: G***; kibuzzard-67C6452E
kibuzzard-67C64429: G***; kibuzzard-67C64429
kibuzzard-67C64532: G***; kibuzzard-67C64532
kibuzzard-681E5A39: G***; kibuzzard-681E5A39
kibuzzard-681E525B: G***; kibuzzard-681E525B

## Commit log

2025-07-01 Initial commit
    Updating from repo template. Adding hardware files & docs template files.
    [SparkFun_Camera_Board_HM01B0.kicad_pcb, SparkFun_Camera_Board_HM01B0.kicad_sch, SparkFun_Pico_Touch_Display.kicad_pcb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]
2025-08-12 Adding annotated photos
    Update to hardware overview pages with annotated photos of Camera and Touch Display boards.

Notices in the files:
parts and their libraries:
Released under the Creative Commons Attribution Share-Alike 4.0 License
